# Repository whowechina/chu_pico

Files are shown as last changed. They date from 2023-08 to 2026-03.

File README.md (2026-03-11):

# Chu Pico - Chunithm Style Mini Controller
[点这里可以切换到中文版](README_CN.md)

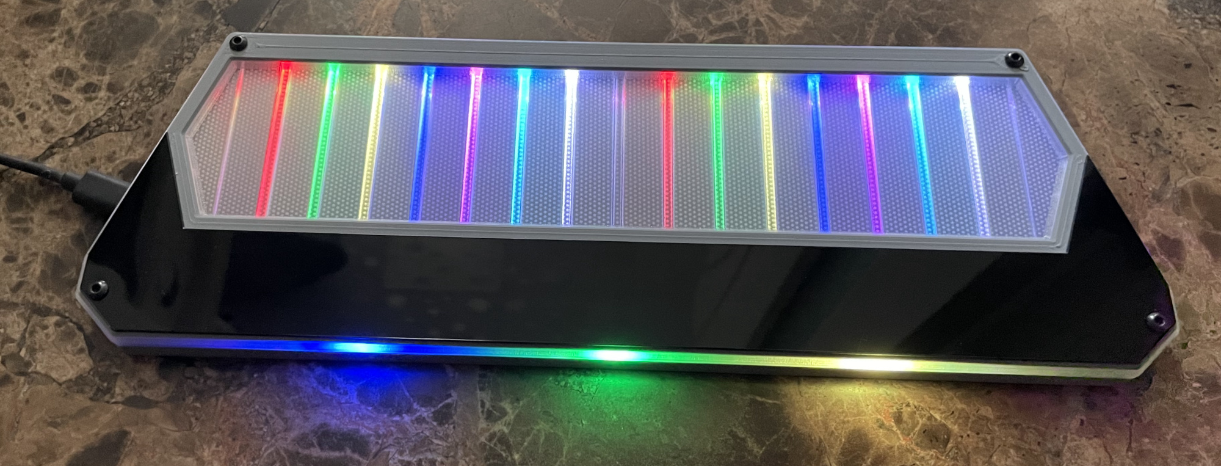
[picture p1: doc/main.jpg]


Features:
* It's small, made for 15-17 inch screen.
* Air towers are replaced with built-in ToF sensors.
* Traditional IR Air mechanism is also provided for DIYers.
* HID lights, of course!
* 32 keys (upper and lower rows).
* Follows CrazyRedMachine's RedBoard I/O protocol.
* Command line of rich features.
* All source files open.

Thanks to many respectful guys/companies who made their tools or materials free or open source (KiCad, OnShape, InkScape, Raspberry things).

And thanks to community developers that inspired me and helped me: CrazyRedMachine (https://github.com/CrazyRedMachine), SpeedyPotato (https://github.com/speedypotato).

And also:
* RP_Silicon_KiCad: https://github.com/HeadBoffin/RP_Silicon_KiCad
* Type-C: https://github.com/ai03-2725/Type-C.pretty

## My Other Projects
You can check out my other cool projects.

               


* Popn Pico: https://github.com/whowechina/popn_pico
* IIDX Pico: https://github.com/whowechina/iidx_pico
* Chu Pico: https://github.com/whowechina/chu_pico
* Mai Pico: https://github.com/whowechina/mai_pico
* Diva Pico: https://github.com/whowechina/diva_pico
* AIC Pico: https://github.com/whowechina/aic_pico
* Groove Pico: https://github.com/whowechina/groove_pico
* Geki Pico: https://github.com/whowechina/geki_pico
* Musec Pico: https://github.com/whowechina/musec_pico
* Ju Pico: https://github.com/whowechina/ju_pico
* Bishi Pico: https://github.com/whowechina/bishi_pico
* Nos Pico: https://github.com/whowechina/nos_pico
* Voltex Pico: https://github.com/whowechina/voltex_pico
* Chord Pico: https://github.com/whowechina/chord_pico
* Dance Pico: https://github.com/whowechina/dance_pico
* Arcade Pico: https://github.com/whowechina/arcade_pico

## **Disclaimer** ##
I made this project in my personal time with no financial benefit or sponsorship. I will continue to improve the project. I have done my best to ensure that everything is accurate and functional, there's always a chance that mistakes may occur. I cannot be held responsible for any loss of your time or money that may result from using this open source project. Thank you for your understanding.

## About the License
It's CC-NC. So DIY for yourself and for your friend, don't make money from it. And plagiarism that doesn’t even dare to mention the original author is not acceptable. Please note that pooling orders and group buying for raw materials is acceptable.Selling any leftover components at cost (without profit) is also acceptable.

If you're interested in buying from me, or for commercial use, please contact me (Discord, QQ group, Goofish).
* My Discord Invitation: https://discord.gg/M8f2PPQFEA
* QQ Group: 854535476
* Goofish: whowe12345

## HOW TO BUILD
### Frequently Made Mistakes
Many DIY enthusiasts commonly make certain mistakes during the building process. Please proceed with extra caution to avoid these.
* **MISTAKE: Soldering everything together without conducting intermediate testing.**  
  Remember, even professional engineers can make mistakes. It becomes significantly harder to identify the root cause of a problem when all components are already assembled or soldered. Therefore, it's advisable to solder and test in stages. The firmware is designed to function correctly even with some components missing, which is good for testing.
* **MISTAKE: Neglecting to cut the ADDR pin trace on the MPR121 module.**  
  The MPR121 module in the market has the ADDR pin pre-connected to ground. But the board expects a floating ADDR pin, otherwise the ADDR pin will short the circuit. Please verify your "CUT" using a multimeter.
* **MISTAKE: Rushing to replace components when something fails.**  
  Sometimes people prematurely assumes that the Raspberry Pi Pico or other modules are faulty.
  Be aware that desoldering and soldering large SMD components is a challenging task. It carries the risk of damaging the component or the PCB board. Patience and caution are crucial. Look at the schematics and PCB design files and ask help from community first. Questioning the integrity of these components should be your last resort.
* **MISTAKE: Failing to properly solder the 2 USB pins of the Raspberry Pi Pico.**  
  These pins are at the bottom side of the PCB. It's a common oversight to either forget to solder them or to leave air bubbles during the process. To avoid this, solder slowly from one side of the hole, using minimal solder wire and a generous amount of flux.

### PCB
* Go JLCPCB and make order with the gerber zip file (latest `Production\PCB\chu_main_xxx.zip`), regular FR-4 board, black color, thickness is **1.6mm**.  
* 1x Rasberry Pico Pi Pico or Pico W.  
  https://www.raspberrypi.com/products/raspberry-pi-pico
  Becareful of 3 pins that are at the other side, they're difficult to solder and may leave air bubbles.  
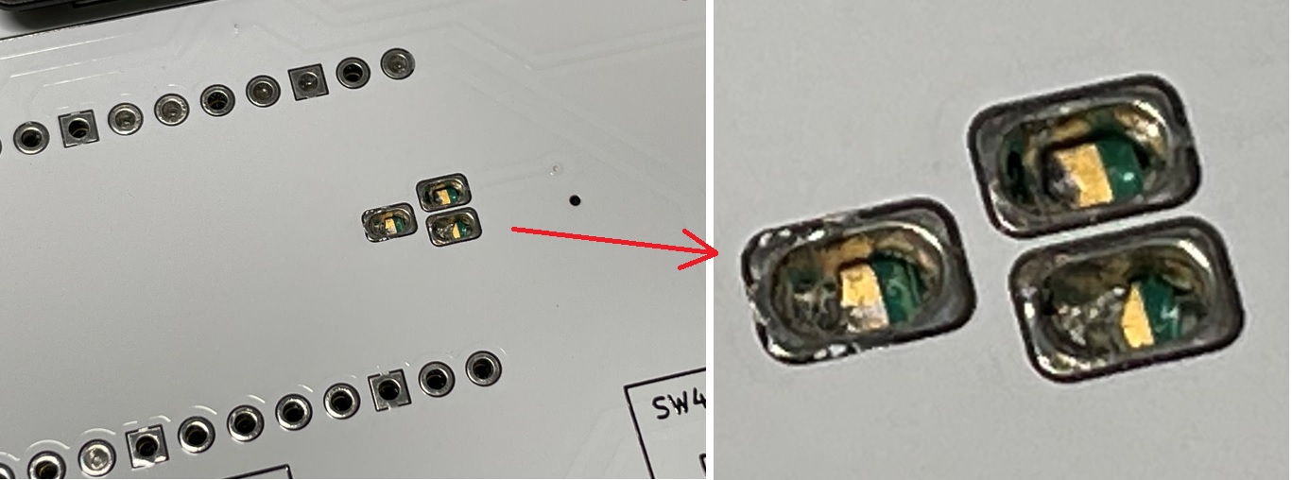
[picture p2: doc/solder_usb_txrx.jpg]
  

* 1x USB Type-C socket (918-418K2023S40001 or KH-TYPE-C-16P)
* 36x WS2812B-4020 side-facing RGB LEDs.  
  https://www.lcsc.com/product-detail/Light-Emitting-Diodes-LED_Worldsemi-WS2812B-4020_C965557.html
* TCA9548APWR (TSSOP-24) I2C multiplexer.  
  https://www.lcsc.com/product-detail/Signal-Switches-Encoders-Decoders-Multiplexers_Texas-Instruments-TCA9548APWR_C130026.html
* 3x MPR121 modules, there're many types in the market, choose ones like this.  
  https://www.sparkfun.com/products/retired/9695  
  Before solder MP121 module to the main PCB board, remember to use a knife to **cut (unshort) the tiny trace that connects ADDR to the GND**. Please be careful not to cut more than necessary.  
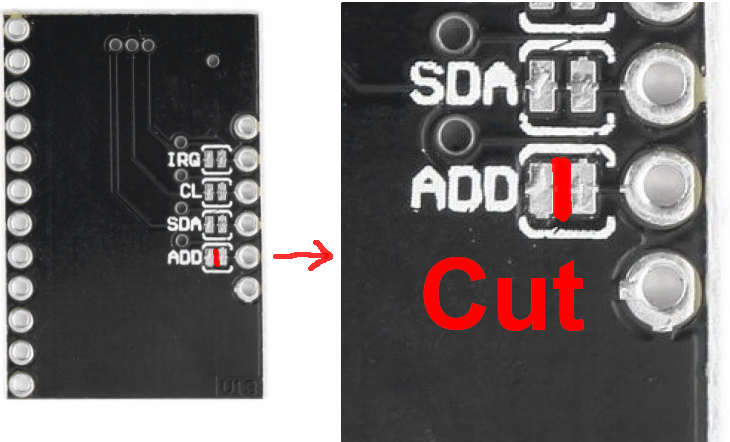
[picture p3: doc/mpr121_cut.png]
    
  There's not enough space for the whole height of MPR121 module plus the lead pads. So you need to solder the module like the picture shows below.  
  First apply some insulation tape.  
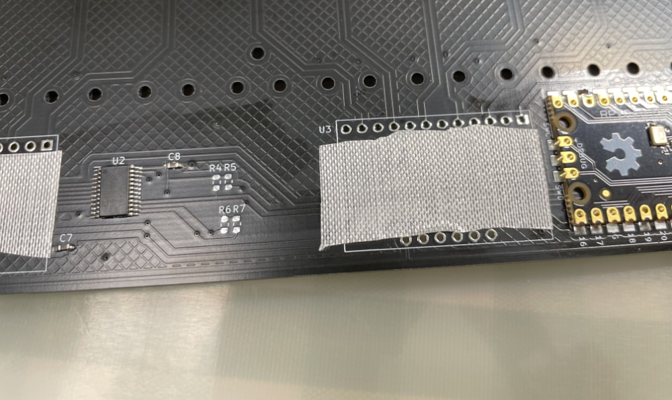
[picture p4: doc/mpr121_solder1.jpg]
    
  Then solder the module directly against the PCB.  
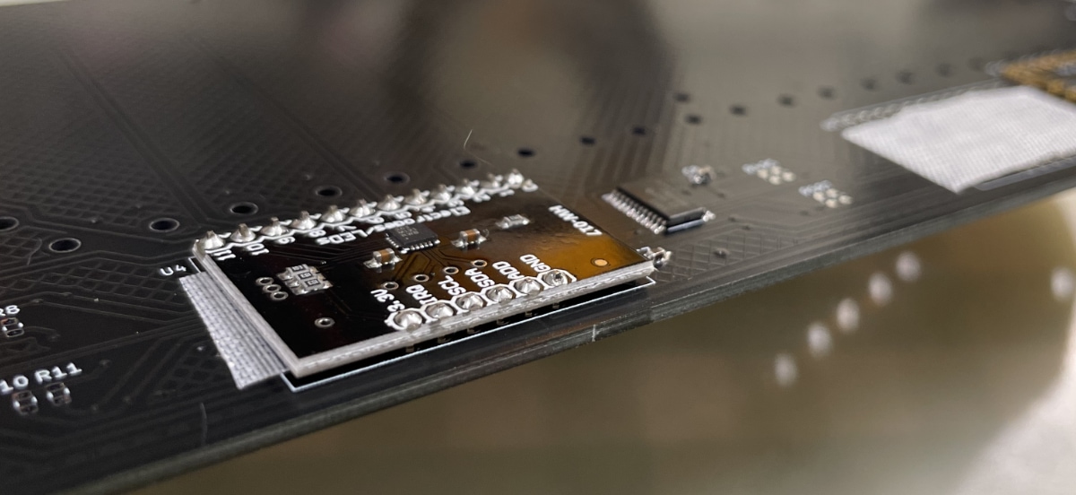
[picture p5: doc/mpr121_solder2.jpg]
    
  You can use the pins comes with the module, but you need to cut away the plastic pads.  
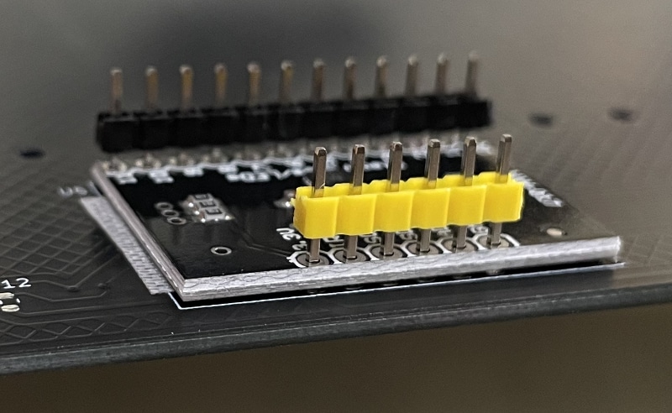
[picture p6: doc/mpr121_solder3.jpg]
  
* 5x Sharp GP2Y0E03 or ST VL53L0X ToF sensor modules, you need cables as well. Please note that the pictures are taken from older version of PCB, the LEDs have been changed to side-facing ones.  
  https://www.lcsc.com/product-detail/Angle-Linear-Position-Sensors_Sharp-Microelectronics-GP2Y0E03_C920270.html  
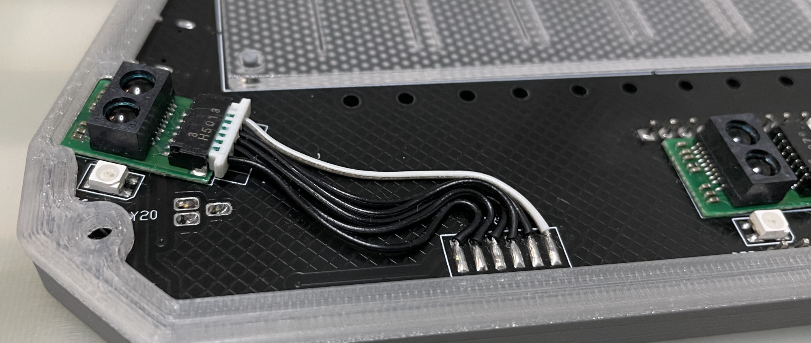
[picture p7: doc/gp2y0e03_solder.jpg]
    
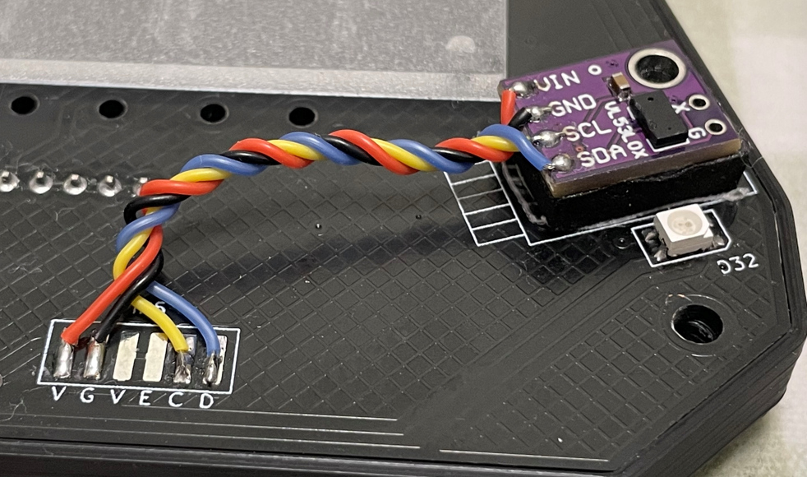
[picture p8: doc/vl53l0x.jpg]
    
   You can use both of them in a same PCB, the firmware will identify each of them automatically.  
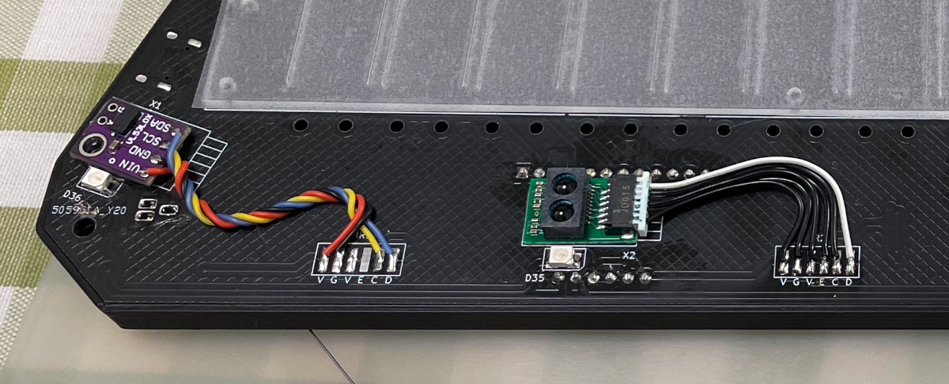
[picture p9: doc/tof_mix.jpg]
  
* 12x 0603 5.1kohm resistors for all the resistors on PCB.
* 8x 0603 1uF (0.1~1uF all fine) capacitors (C1 to C8), OPTIONAL, recommended.
* 3x Panasonic EVQP46B3M tiny tactile switches.  
  https://industry.panasonic.com/global/en/products/control/switch/light-touch/number/evqp46b3m

### Light Guide Panel
* Find a service to cut a light guide panel using DXF or DWG file `Production\CAD\chu_pico_lgp.*`, the size is 256mm*60mm, 1.8mm to 2.0mm thickness, thinner is better for sensitivity. 2.0mm is easy to find, 1.8mm is rare. I used 1.8mm for my build.  
  
* LGP material choices:
  * Real LGP (Light Guide Panel) material, it's the best choice.  
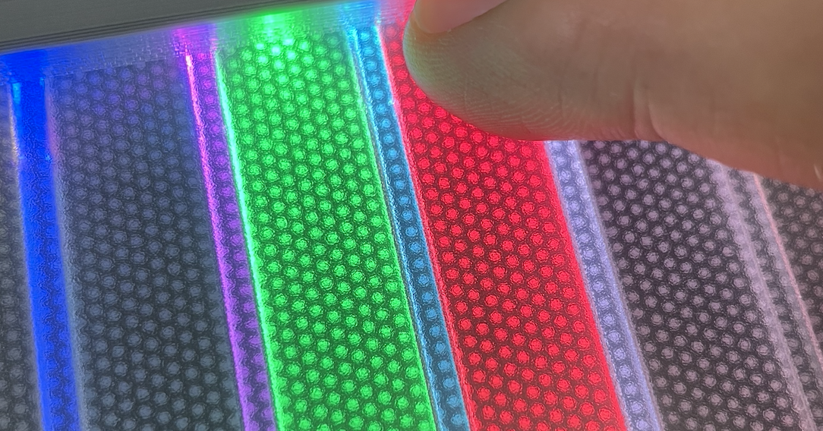
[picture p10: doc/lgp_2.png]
    
  * Clear Acrylic with Light Guide Film, it's a good choice.  
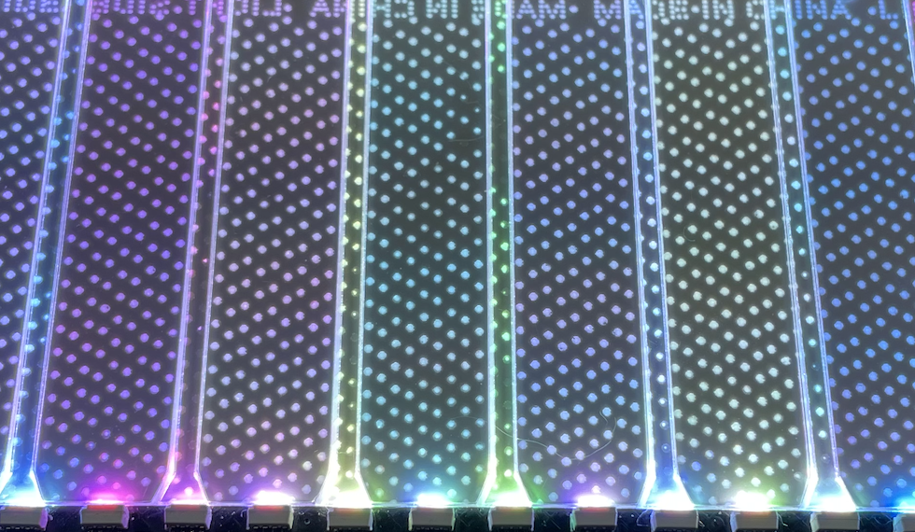
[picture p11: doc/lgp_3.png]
    
  * Clear Acrylic with single-side-frosted, it's a good choice.  
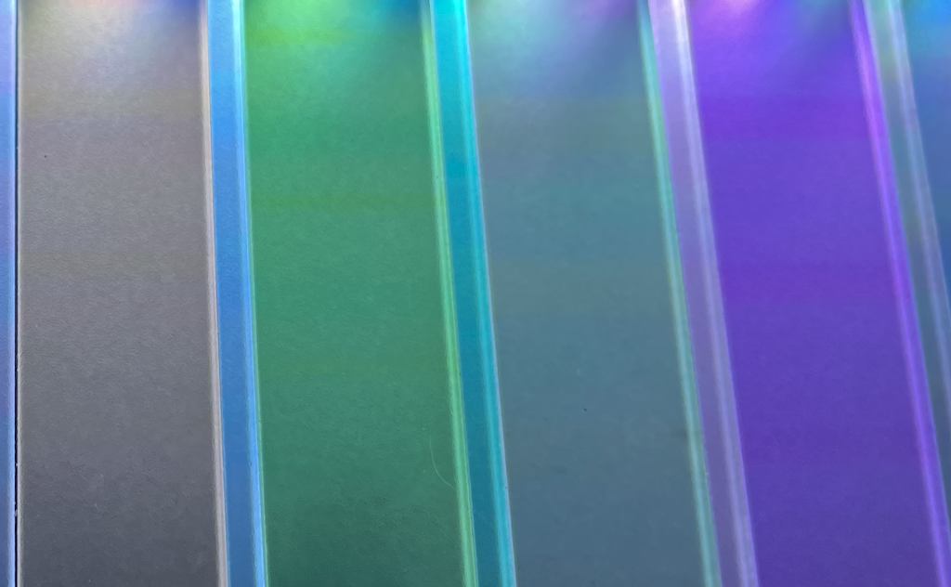
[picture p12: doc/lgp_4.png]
    
  * Clear Acrylic with manual single-side-sanding, it can work too.  
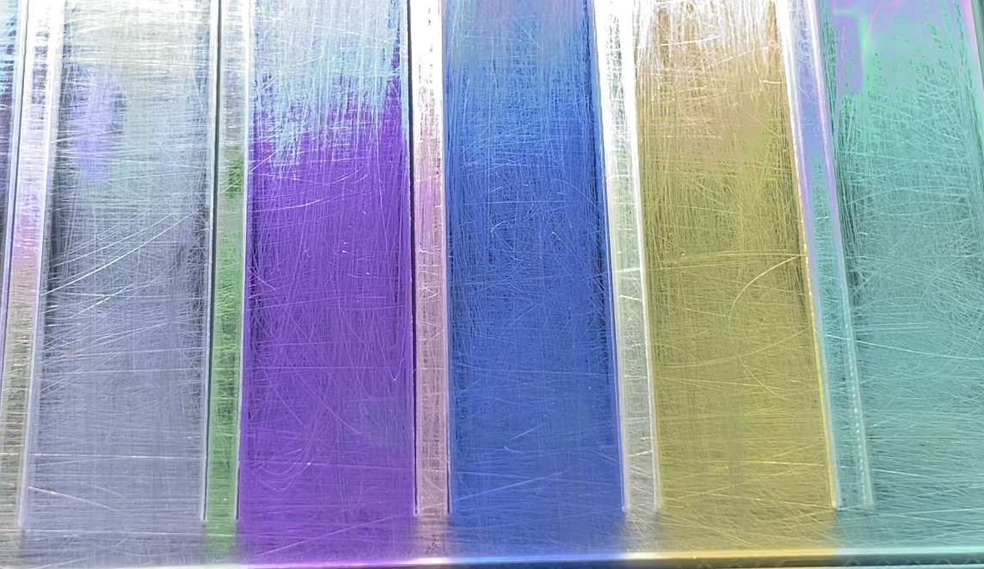
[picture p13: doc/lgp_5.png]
    

### Panel Film
* A self-adhesive **textured**/**frosted** film sheet, it is applied on top surface of the light guide panel. It improves touch feel. You can use window sticker film. It **MUST** be self-adhesive ones, **NOT** static cling ones. They're usually very cheap.
* Cut the film to roughly match the shape of the light guide panel, and stick to the panel.  
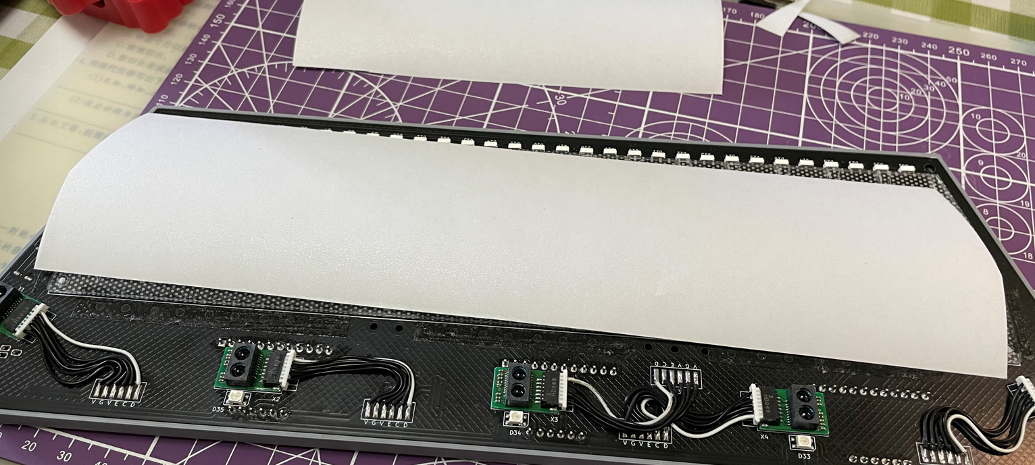
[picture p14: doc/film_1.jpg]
  
* Gentlely rub the film to remove any air bubbles and make it stick tightly.  
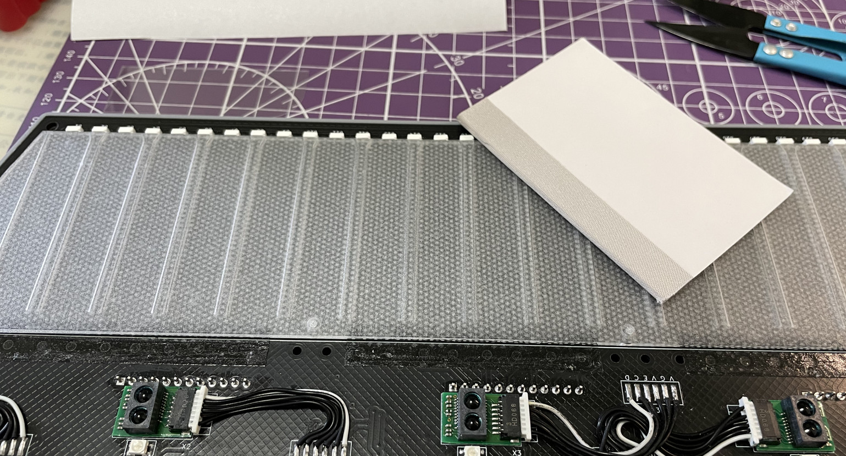
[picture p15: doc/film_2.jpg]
  

###  IR Cover
* It's for good looking, as it hides 5 ToF sensors.   
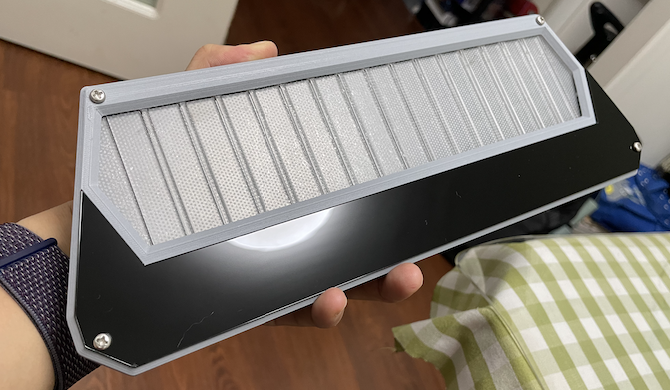
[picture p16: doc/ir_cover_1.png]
  
* IR lights can go through.  
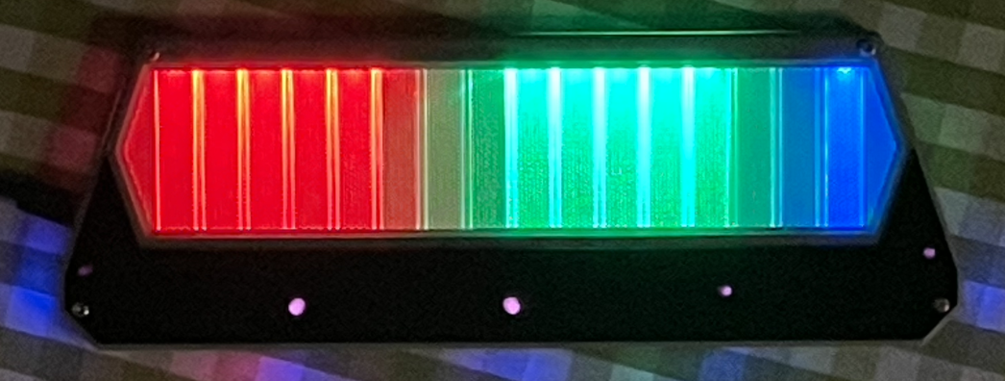
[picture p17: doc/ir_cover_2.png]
  
* Find a service to cut an IR cover using the DXF or DWG file `Production\CAD\chu_pico_ir_cover.*`, the size is 293.2mm*63.5mm, 1mm thickness. The material must be "Infrared Transmitting Acrylic Sheet" which can block visible lights (so it looks black) while letting IR lights go through.  
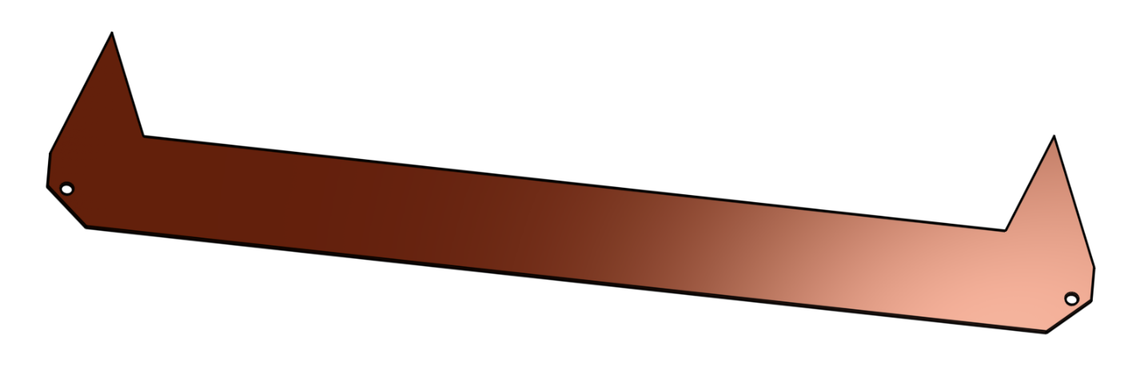
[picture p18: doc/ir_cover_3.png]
  
* If you can't find one, cut a regular smooth surface acrylic, but it can't hide the ToF sensors which are not good looking.
* If you're using the VL53L0x ToF sensor, please add padding beneath the sensor. This brings it closer to the acrylic cover, which can prevent acrosstalk error.

### 3D Printing
* You need a Bambu 3D printer for 2 reasons:
  * Parts are designed to perfectly fit in its 256mm*256mm print bed.
  * Its AMS system works great for easy-to-remove support material.
* For all the following prints:
  * To fit object in the bed, Z rotate: 315 degree, X, Y move to: 134mm  
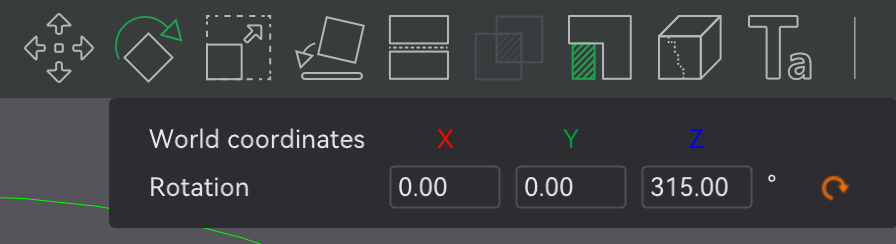
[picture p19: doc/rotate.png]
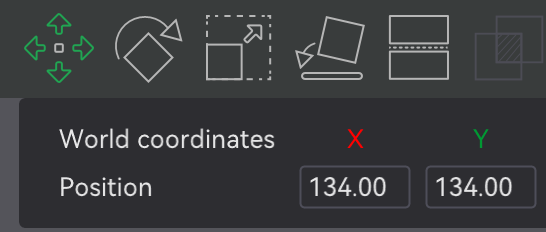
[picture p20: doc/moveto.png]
    
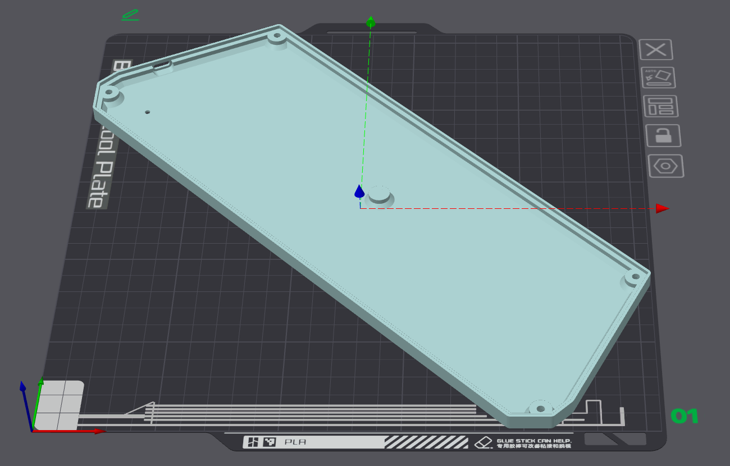
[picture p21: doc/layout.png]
  
  
  * PLA, PETG, ABS are all OK.
  * Layer height: 0.2mm
  * 4-6 walls, 50+% infill
  * Support: No (unless specified).

* Base: `Production\3D\chu_pico_base.stl`, dark gray filament, turn on support to have better screw holes.
* Cover: `Production\3D\chu_pico_cover(_aime).stl`, dark gray filament, print up-side down.
* Cover Base: `Production\3D\chu_pico_cover_base.stl`, **clear transparent (IMPORTANT)** filament.
* Light Guide Panel Fixer: `Production\3D\chu_pico_lgp_fixer.stl`, color doesn't matter.

### Exploded View for Assembly
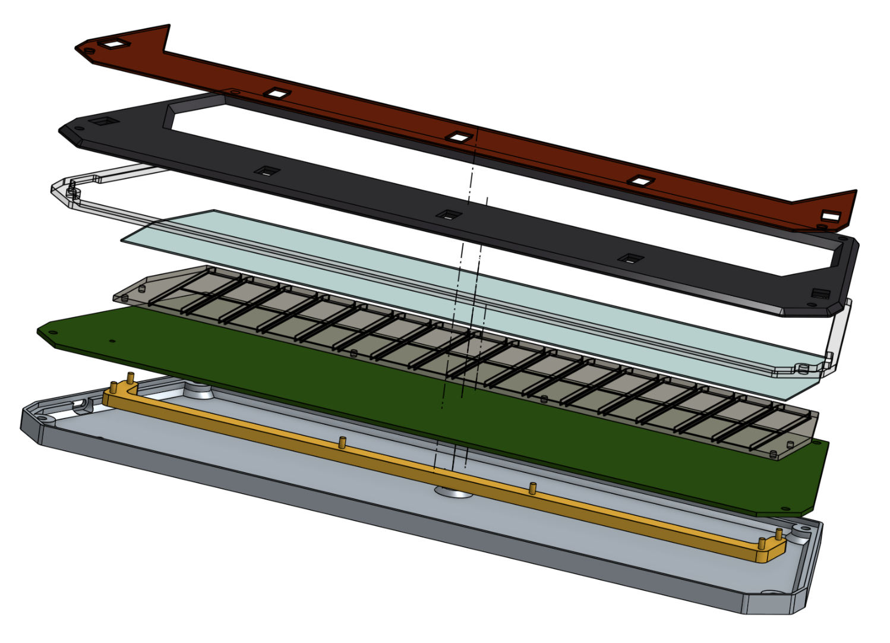
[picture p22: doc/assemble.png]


From top to bottom:
* IR Cover
* Cover
* Cover Base
* Panel Film
* Light Guide Panel
* PCB
* Light Guide Panel Fixer
* Base

You need **4x M3*12mm screws and 4x M3 hex nuts** to fix all things.

7x silicone anti-slip pads can be applied to the bottom side of the base to provide stability when playing.  
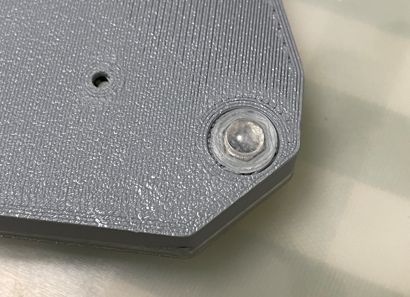
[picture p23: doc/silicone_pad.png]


### IR Air Tower
This is not necessary for Chu Pico. But some people may prefer the traditional IR air tower, especially when they're using Chu Pico design for a full-sized controller.
So hereby I provide the IR air tower design, with a pair of air tower PCBs and the firmware support.
1. First, you need to order the sensor PCBs, the gerber file is `Production\PCB\chu_air_v*.zip`. It's for both sides of the air tower.
2. Solder components to the PCB following the silkscreen. About the components, see the notes below.
3. For left side PCB, use J1 to connect to the Raspberry Pi Pico, and for the right side PCB, use J2. GPIO 3 -> A, GPIO 4 -> B, GPIO 5 -> C, ADC 0 (GPIO 26) -> Right S, ADC 1 (GPIO 27) -> Left S.  
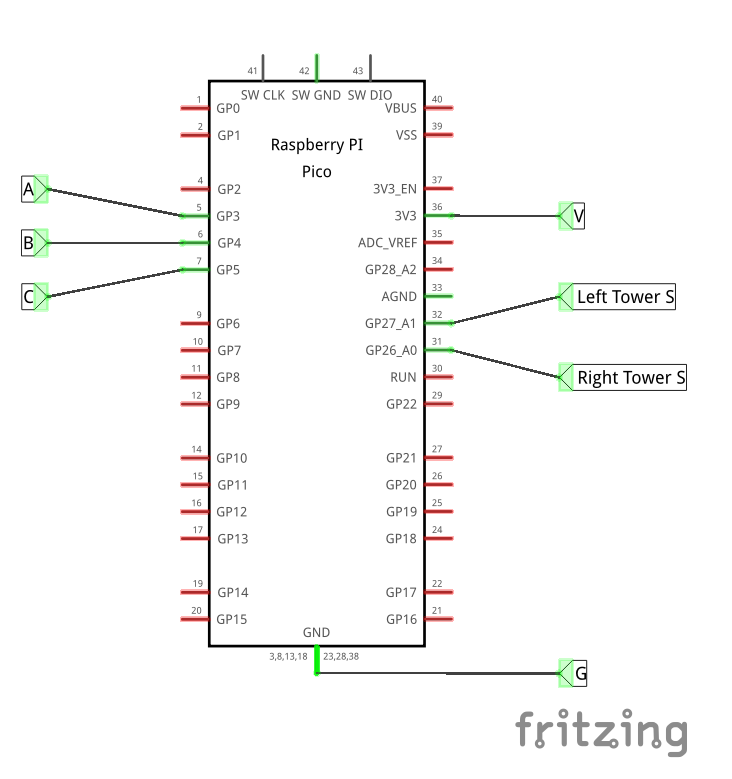
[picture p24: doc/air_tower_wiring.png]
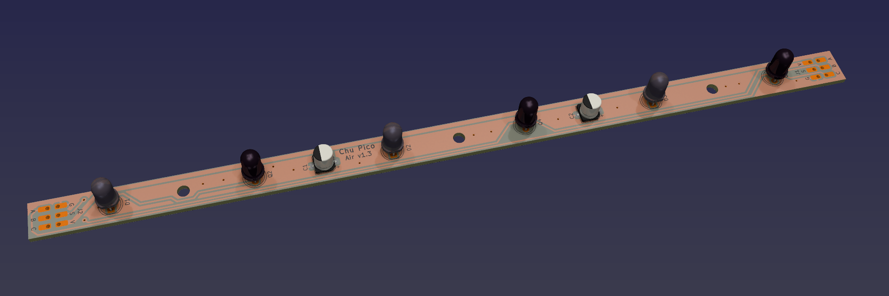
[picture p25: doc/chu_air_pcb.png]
   

4. Steps for deployment.
   * Enable IR sensor in the firmware (command `ir enable`), this will disable ToF.
   * Enable diagnostics for IR (command `ir diagnostic`).
   * Orientation of the PCB: for the left side PCB, its J1 is at the lowest, for the right side PCB, its J2 is at the lowest (up-side-down).
   * Place the air towers and watch the output of the diagnostics, higher value means beam is received.
   * Set the baseline after the towers are properly placed (command `ir baseline`).
   * Optionally, set the sensitivity, it's a percentage of expected change (command `ir trigger <1..100>`).

#### Notes for the Components
* D1, D2, D3 are IR333C-A IR LEDs;
* Q2, Q4, Q6 are PT333-3B phototransistors.
* Q1, Q3, Q5 are N-Channel MOSFETs with low Rds, such as AO3400, see calculations below.
* R2, R4, R6 are current limiting resistors, see calculations below.
* R1, R3, R5 are mosfet gate resistors, 10ohm is fine.
* R7, R8, R9 are pull-up resistors, 2Kohm is fine.
* R10 is a pull-down resistor, 10Kohm is fine.

* Let's do the calculation for D1 as an example. To get proper signal strength, we want about 1A current for it.  
  The current for D1 is calculated by `I = (Vcc - Vf) / (Rds + R2)`. Vcc is 3.3V, Vf is the forward voltage of D1 (about 2.6V@1A). For a low Rds N-Channel MOSFET such as AO3400, Rds is about 0.047ohm, so R2 should be about 0.7ohm to get 1A current. You can use other N-Channel MOSFETs, but you need to calculate the values accordingly.

### Firmware
* UF2 file is in `Production\Firmware` folder.
* For the new build, hold the BOOTSEL button while connect the USB to a PC, there will be a disk named "RPI-RP2" showed up. Drag the UF2 firmware binary file into it. That's it. There's a small hole at the bottom side of the Chu Pico, it is facing right to the BOOTSEL button.
* It works on CrazyRedMachine's RedBoard protocol. For more information, please check out CrazyRedMachine's project (Don't forget to give him a star and drop by his GitHub for other cool projects):  
https://github.com/CrazyRedMachine/RedBoard
* It has a command line to do configuration. You can use this Web Serial Terminal to connect to the USB serial port of the Chu Pico. (Note: "?" is for help)  
  https://googlechromelabs.github.io/serial-terminal/  
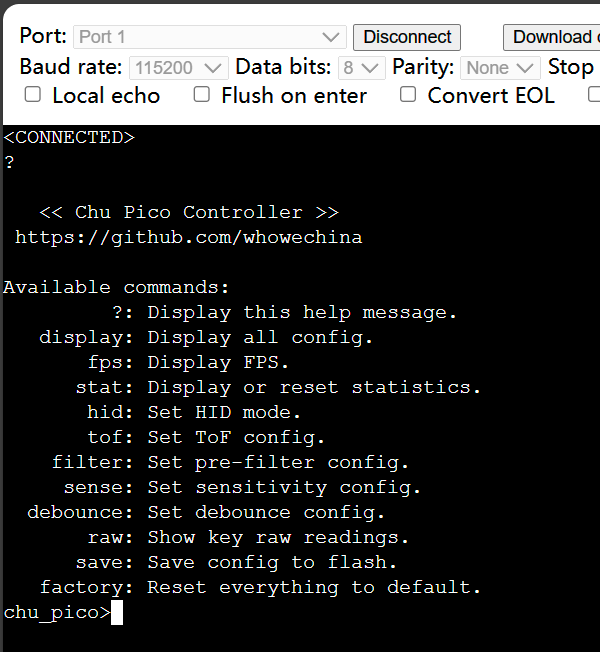
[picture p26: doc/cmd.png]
  

## CAD Source File
I'm using OnShape free subscription. It's powerful but it can't archive original designs to local, so I can only share the link here. STL/DXF/DWG files are exported from this online document.  
https://cad.onshape.com/documents/8b9d0fe6ff1bfa4da17d33ee/w/5c7c980a282a19e7ba1db795/e/56ee65492584a3f709c23c49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

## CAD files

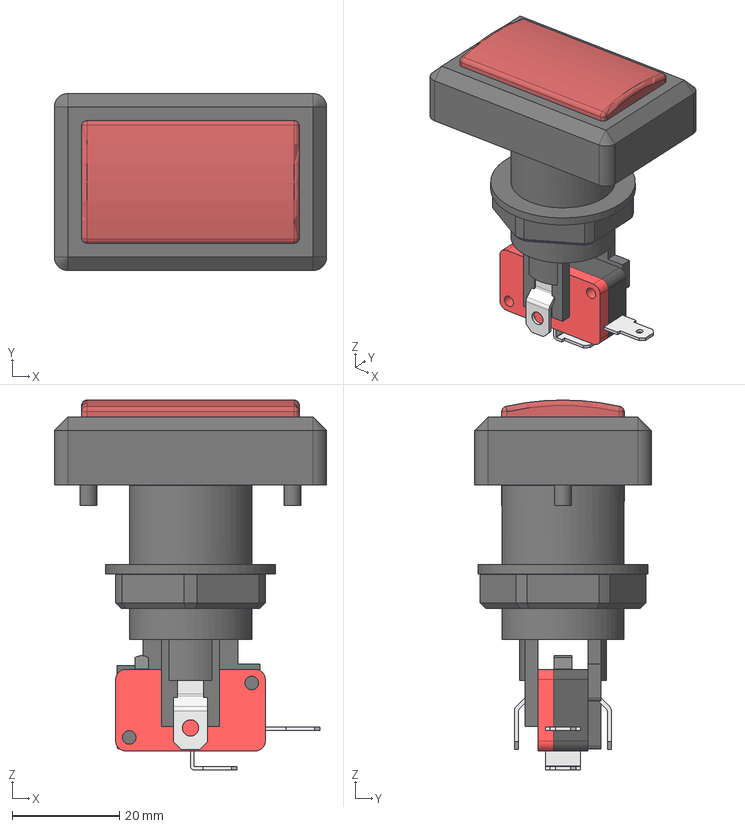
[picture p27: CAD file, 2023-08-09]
PCB/main/3dmodels/Credit Button Assy (Groovy).step
50.8 x 33.0 x 69.0 mm
Button
Nut
Switch

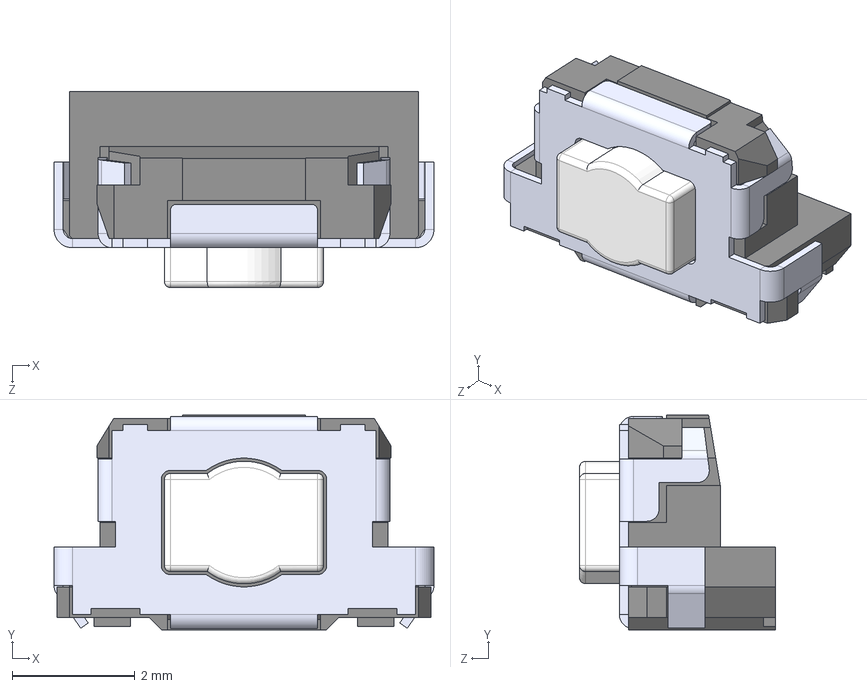
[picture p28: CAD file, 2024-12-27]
PCB/main/3dmodels/EVQ-P46B3M.step
6.20 x 3.50 x 3.20 mm

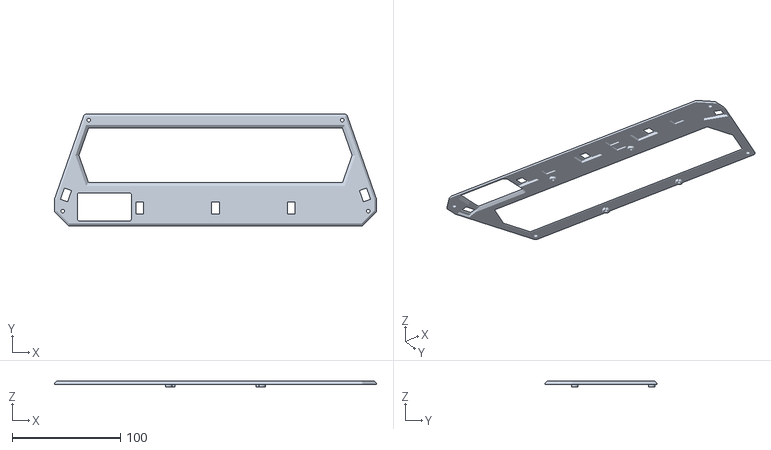
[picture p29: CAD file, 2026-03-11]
Production/CAD/chu_pico_cover_aime.stl
297.2 x 103.2 x 5.20

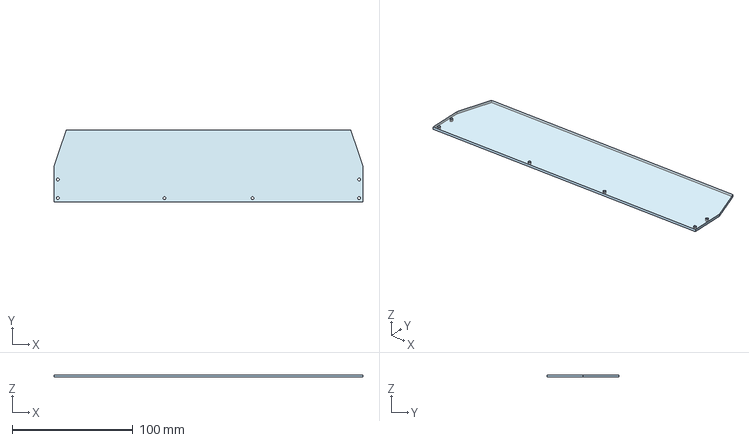
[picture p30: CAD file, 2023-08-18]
PCB/main/3dmodels/chu_keypad_lgp.step
256.0 x 60.0 x 2.00 mm

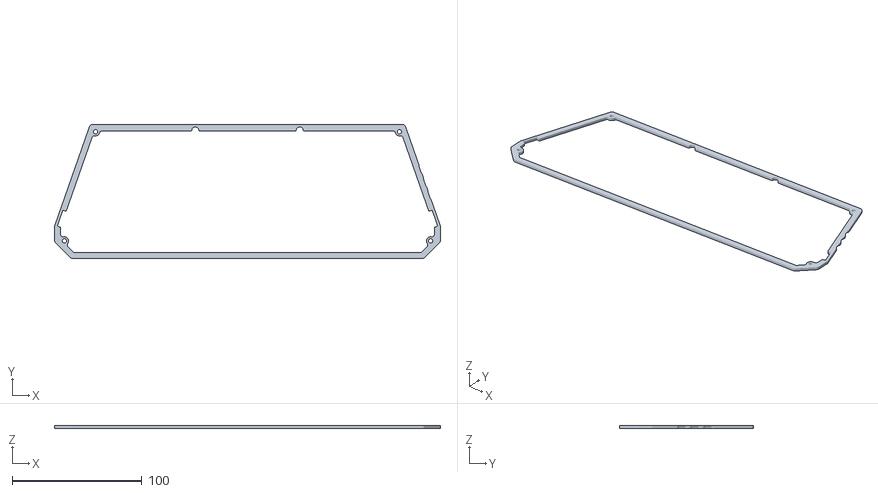
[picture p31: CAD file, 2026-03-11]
Production/CAD/chu_pico_support.stl
297.2 x 103.2 x 2.20

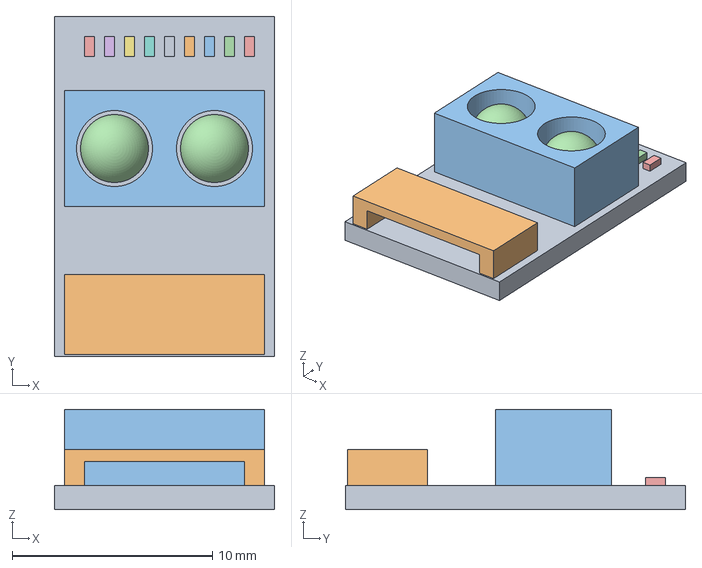
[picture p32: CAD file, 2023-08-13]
PCB/main/3dmodels/gp2y0e03.3mf
11.0 x 17.0 x 5.00 mm

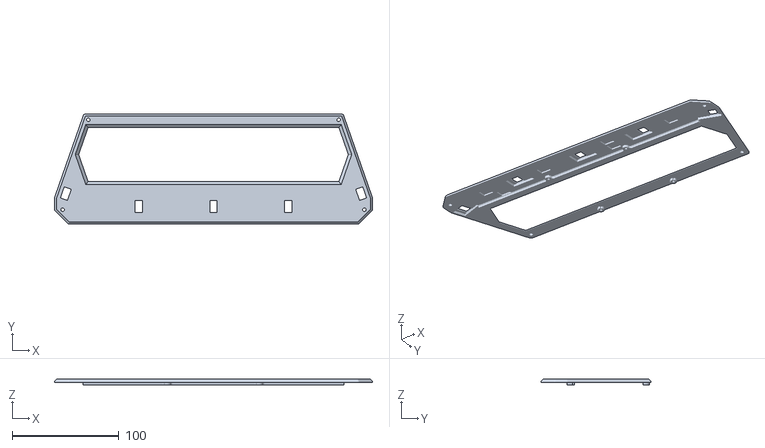
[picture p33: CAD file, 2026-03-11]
Production/CAD/chu_pico_cover.stl
297.2 x 103.2 x 5.20

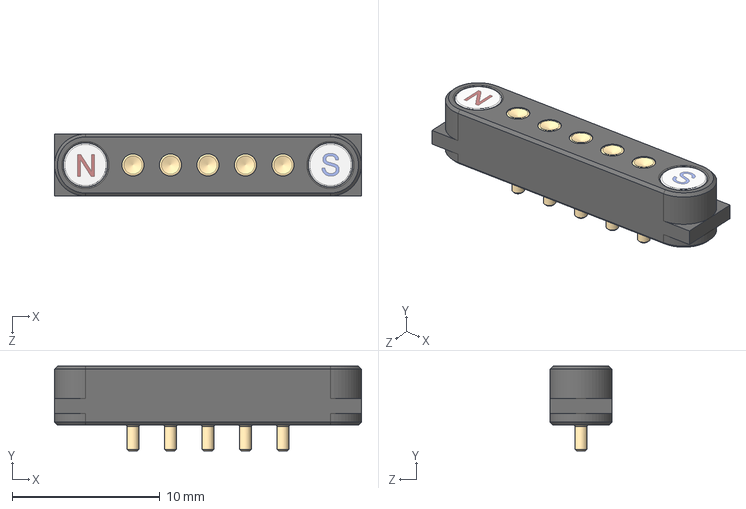
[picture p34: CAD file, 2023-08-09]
PCB/main/3dmodels/Magnetic Pogo Connector 5 Pin (F).STEP
20.8 x 5.75 x 4.20 mm

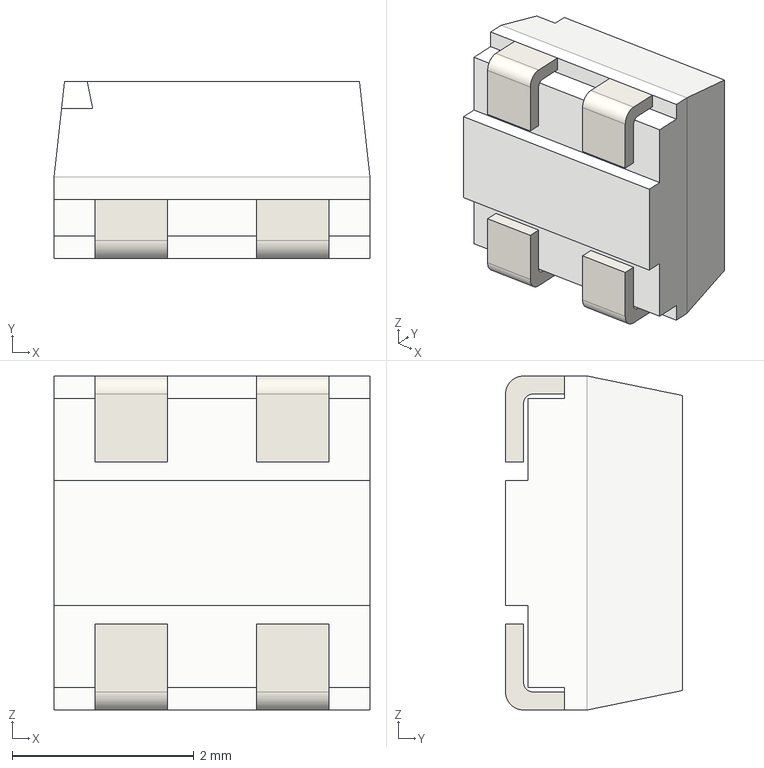
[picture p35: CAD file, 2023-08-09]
PCB/main/3dmodels/SMD WS2812B-3535.step
3.48 x 1.95 x 3.68 mm

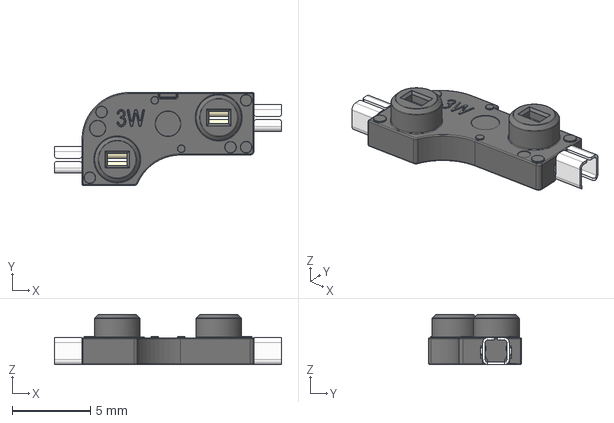
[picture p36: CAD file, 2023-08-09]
PCB/main/3dmodels/SW_Hotswap_Kailh_MX.stp
14.5 x 5.95 x 3.22 mm

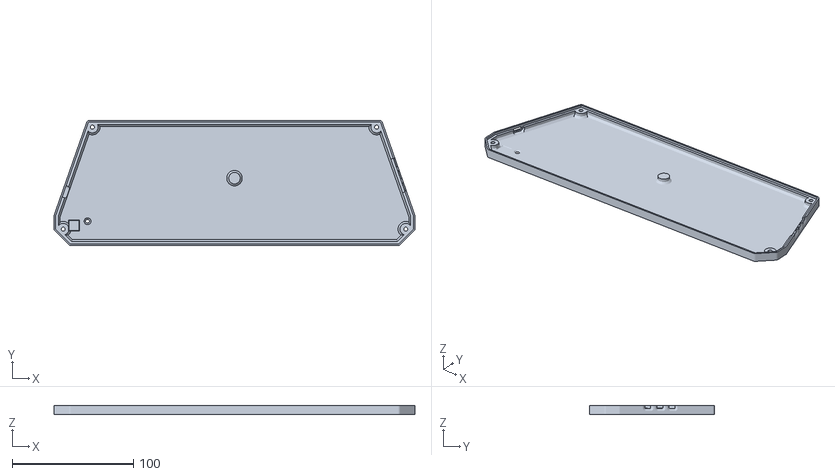
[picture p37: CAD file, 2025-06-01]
Production/CAD/chu_pico_base.stl
297.2 x 103.2 x 7.20

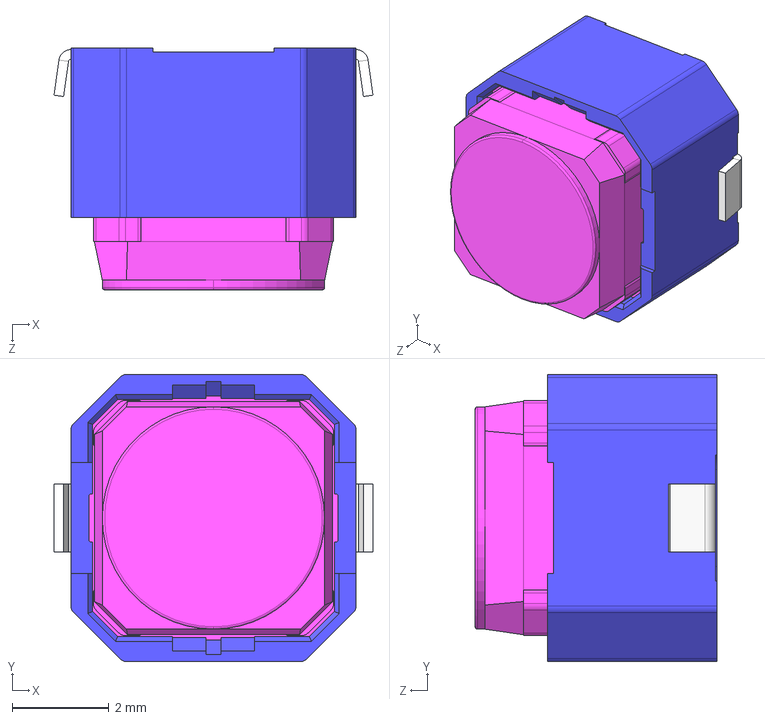
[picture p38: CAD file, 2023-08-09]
PCB/main/3dmodels/SKPMAM.STEP
6.60 x 5.94 x 5.00 mm

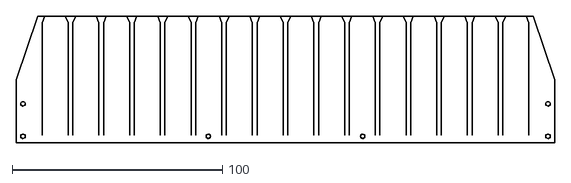
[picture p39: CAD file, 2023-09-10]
Production/CAD/chu_pico_lgp.dxf
256.0 x 60.0

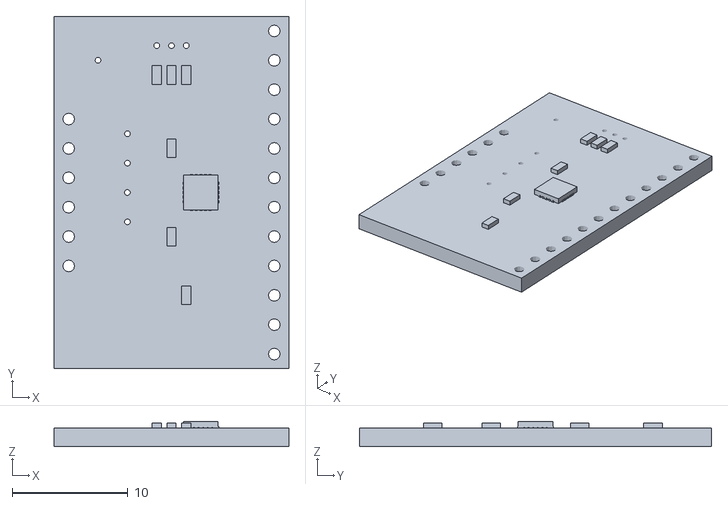
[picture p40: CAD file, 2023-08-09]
PCB/main/3dmodels/mpr121_breakout_v13.stl
20.3 x 30.5 x 2.20

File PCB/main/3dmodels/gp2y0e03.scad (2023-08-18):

$fn=64;
translate([-5.5,-8.5]) color("darkgreen") cube([11,17,1.2]);

color("#202020") difference() {
  translate([-5,-8.4]) cube([10,4,3]);
  translate([-4,-9.3]) cube([8,4,2.4]);
}

color("#303040") difference() {
  translate([-5,-1]) cube([10,5.8,5]);
  translate([2.5,1.9,3]) cylinder(d=3.8,h=10);
  translate([-2.5,1.9,3]) cylinder(d=3.8,h=10);
}
color("#602020") {
  translate([2.5,1.9,3.2]) sphere(d=3.4);
  translate([-2.5,1.9,3.2]) sphere(d=3.4);
}
  
for (i = [-4:1:4]) {
  color("yellow") translate([i,6.5,1]) cube([0.5,1,0.6]);
}

for (i = [-4:1:4]) {
  color("silver") translate([i-0.2,-1.8,0.8]) cube([0.5,1,0.6]);
  color("silver") translate([i-0.2,4.6,0.8]) cube([0.5,1,0.6]);
}

for (i = [-4:1.3:4]) {
  color("silver") translate([i-0.3,-5,1]) cube([0.6,2,0.6]);
  color("silver") translate([i-0.6,-7,2]) cube([0.2,2,0.6]);
}

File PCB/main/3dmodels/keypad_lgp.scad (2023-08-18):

color("silver",0.5) translate([-17,-130]) resize([256,60,1]) linear_extrude(h=100) import("keypad_kicad.svg");

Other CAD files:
PCB/main/3dmodels/iidx_keycap_main_step.stp
Production/CAD/chu_pico_cover_insert.stl
Production/CAD/chu_pico_cover_insert_aime.stl
Production/CAD/chu_pico_ir_cover.dxf
PCB/main/3dmodels/EVQ-P1D05M.stp
PCB/main/3dmodels/J 2835.step
PCB/main/3dmodels/Kailh LP Choc PC Keycap.step
PCB/main/3dmodels/Magnetic Pogo Connector 5 Pin (M) - 副本.STEP
PCB/main/3dmodels/Magnetic Pogo Connector 5 Pin (Type 2).STEP
PCB/main/3dmodels/Magnetic Pogo Connector 5 Pin (Type 3).STEP
PCB/main/3dmodels/Magnetic Pogo Connector 5 Pin (Type 4).STEP
PCB/main/3dmodels/SW_Hotswap_Kailh_Choc_V1.stp
PCB/main/3dmodels/SW_Kailh_Choc_V1.stp
PCB/main/3dmodels/Tact Switch 4.5mm SMT.step
PCB/main/3dmodels/User Library-PTS645SL95SMTR92-LFS.STEP
PCB/main/3dmodels/User Library-WS2812-2020.step
PCB/main/3dmodels/User Library-WS2812-4020.step
PCB/main/3dmodels/User Library-pj-393-8.STEP
PCB/main/3dmodels/WS2812-0807.STEP
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

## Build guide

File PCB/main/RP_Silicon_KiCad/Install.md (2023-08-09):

# Install KiCad libraries

## Manage Symbol Libraries

Accessed from the Preferences menu, add a new line with the +, give it a name and use the folder icon to point to the directory/folder where you have KiCadLibraries.

Manage Symbol Libraries screen shot


## Manage Footprint Libraries

Ditto! Accessed from the Preferences menu, add a new line with the +, give it a name and use the folder icon to point to the directory/folder where you have KiCadLibraries.

Manage Footprint Libraries screen shot


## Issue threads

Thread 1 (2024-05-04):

is there a proper tutorial or method

zendon180, 2024-05-04:
just the title

zendon180, 2024-05-04:
also how does it register input? there is no touch sensor?

whowechina, 2024-05-04:
Of course there's touch sensor: capactive sense.
The readme in both EN and CN is the guide telling you how to build one.
But there won't be anything related to game data related thing.

zendon180, 2024-05-05:
oh wait i think my question was wrong what i meant to say is something more like, the touch sensors aren't under the keys so how does it register?

whowechina, 2024-05-05:
I see. So it's about "how the touch sensors work". The touch sensors (electrodes) are actually under the slider panel, built-in with the PCB. Search for MPR121 datasheet, or search "capsense", you'll understand.

zendon180, 2024-05-06:
thanks for the response i was thinking if it was something like that

Closed 2024-05-04.

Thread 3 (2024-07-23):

chuniio.dll problem

sksjndn3, 2024-07-23:
i edit segatools io to [chuniio.dll](urlhttps://github.com/whowechina/chu_pico/blob/main/tools/chuniio.dll) and the game even cannot run,the error see as the photo
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

sksjndn3, 2024-07-23:
用的tools里的chuniio.dll，怎么试都报这个错

whowechina, 2024-07-23:
跑的是 redboard 的协议，用 redboard.dll。

Closed 2024-07-23.

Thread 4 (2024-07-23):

LED problem

sksjndn3, 2024-07-23:
Chinese plz。
刷了led测试程序，在d13就不亮了，万用表测了下正常导通，灯也换了好几个，就是d13往后都不亮，是不是程序有问题
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

whowechina, 2024-07-23:
信号是串联传递的，一般 D13 故障，就要同时看 D12/D13 的焊接。

sksjndn3, 2024-07-23:
我用万用表打了导通挡，全引脚都是正常导通的，还是不亮

sksjndn3, 2024-07-23:
我再排除一下吧，谢谢大佬回复

whowechina, 2024-07-23:
> 我再排除一下吧，谢谢大佬回复

除了“通”，要关注不应该通的，比如 D12 通往 D13 的数据线，不应该碰上 G 或者 V。

Closed 2024-07-23.

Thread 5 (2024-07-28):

i2c/touch problem

sksjndn3, 2024-07-28:
我在焊接完毕后，烧录chupico固件后注意到灯乱闪，然后拆焊下来，在chuntest测试程序里发现一直在凭空触发所有区块，随后我又拿了一片完全全新的树莓派pico烧录chupico固件，也是这样乱跳，我找不到解决方案，多次重刷固件也无果
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

whowechina, 2024-07-29:
Touch 传感由 MPR121 模块完成，这个模块未连接或者连接故障就会导致错误的触摸检测。
使用命令行里面的多个命令，尤其是“raw”来进行调试，正常情况下，各个电极感应数据都在 850-900 附近。
因为这个不是 Chu Pico 本身的问题，我就关闭这个 Issue 了。

sksjndn3, 2024-07-29:
好的吧，那我再排查一下3个mpr模块的问题，不过之前焊的两片板子都是通电正常亮灯来着

sksjndn3, 2024-07-29:
也不对吧，我先前焊的四片pcb都是先测灯光完好性再焊触摸模块的，也没这样抽风闪灯😢

whowechina, 2024-07-29:
灯光测试有一个专门的 UF2 文件，它不读触摸，仅仅点灯。
触摸模块或者 I2C 故障的时候，现象是随缘的。

sksjndn3, 2024-07-31:
这问题很玄乎啊，3片mpr都是没有故障的之前焊的板子都是先测灯再上触摸，也没见这种抽搐，上了完好触摸也无济于事，raw读数照样抽风，进test也乱闪
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

这是另一片没焊触摸，触摸灯光和raw读数完全正常
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

whowechina, 2024-07-31:
使用chu_pico_led_test.uf2进行led测试，这个固件也只能测试led。

触摸故障的话，记得mpr121模块本身坏的概率极其低，更多是焊接，割addr线等事情。电子制作嘛，啥失误都可能。

sksjndn3, 2024-07-31:
不对不对，我是说触摸数据在没有焊触摸模块的时候乱跳，这就说明锅甩不到mpr头上，何况焊了和没焊的乱跳表现都是一样的😞

whowechina, 2024-07-31:
没焊好，或者没挂模块，都是一回事，都是触摸故障。 具体现象根据i2c俩引脚环境随缘了。在 2024年7月31日，22:48，sksjndn3 ***@***.***> 写道：
不对不对，我是说触摸数据在没有焊触摸模块的时候乱跳，这就说明锅甩不到mpr头上，何况焊了和没焊的乱跳表现都是一样的😞

—Reply to this email directly, view it on GitHub, or unsubscribe.You are receiving this because you modified the open/close state.Message ID: ***@***.***>

Closed 2024-07-29.

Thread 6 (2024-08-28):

There's just two problem.

crazyforsf, 2024-08-28:
Using a translator. I'm Korean.

=================================================================

I think using a ToF sensor is a pretty good idea, but there are two problems with this form.

-
First, if the air sensor is being recognized in the 'center' and the touch has to be crossed with the other hand, the air sensor recognition is blocked by the other arm.
(ex : gengaozo expert, screenshot)
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

Of course, being aware of that part, I can move my hand to the air sensor, but it is quite difficult to do so during complex processing of high difficulty level - master level 13+ or higher.

Therefore, it is good to use a ToF sensor, but I think it would be a better choice to have separate key assignment options or builds for each sensor, rather than depending on the 'height' of the ToF sensor.
(By placing the ToF sensor sideways like a conventional IR sensor)

-
Secondly, this is not a problem for this small controller, but if you make a full size controller the number of tof sensors is not enough.

There are some empty spaces in between.

Therefore, it is judged to be a good idea to allocate the maximum connection value of the TCA9548APWR chip to the ToF sensor. From the current 5 to the maximum of 8.

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

This is Openithm+chupico, which I created by modifying various things myself.
(Never mind that there are six sensors. It's not working right now so I've reduced it back to 5.)

It's arcade full size, and I think it works pretty well.

===================================================================

This is just a suggestion, and there is no pressure to ask why not make the offer.
I just think it would be better if these areas were improved.

whowechina, 2024-08-28:
Hey, thanks for the feedback.
For the first problem, I can't do anything so far. Honestly I don't see a solution there for such a small con.
For the second problem, you can check my chu_arcade repo. I used 10+ ToF sensors for my arcade size con.

https://github.com/user-attachments/assets/cb141b87-1fb6-4556-abc9-fbacf5f58e4d

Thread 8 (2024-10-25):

air乱序

ifaming, 2024-10-25:
你好，我发现使用tof模式下的air从下往上触发顺序是2 3 4 1 5 6，而不是1 2 3 4 5 6，这是故意这样设计的还是说这是一个bug？

whowechina, 2024-10-26:
按照 redboard chunio 来的。

whowechina, 2024-10-26:
我确认后会修改。

whowechina, 2024-11-02:
感谢，确实有问题，我已经修复。

Thank you. I've fixed it in latest commit.

Closed 2024-11-02.

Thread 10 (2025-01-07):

tof sensors not working

GuardianGuy, 2025-01-07:
I'm using [these](https://www.aliexpress.us/item/3256807013376106.html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) ST VL53L0X tof sensors (the blue ones) and I can't get them to sense anything, the CLI shows them all at 0 no matter what I put in front of them or what I set the offset or pitch to.  The rest of the controller works as intended and I've checked and re-checked the wiring and I can't find any issues there.
Could this be a firmware issue with not detecting which sensor is being used?

whowechina, 2025-01-07:
I don't think it's a firmware issue.
Maybe check the mux.

Closed 2025-01-07.

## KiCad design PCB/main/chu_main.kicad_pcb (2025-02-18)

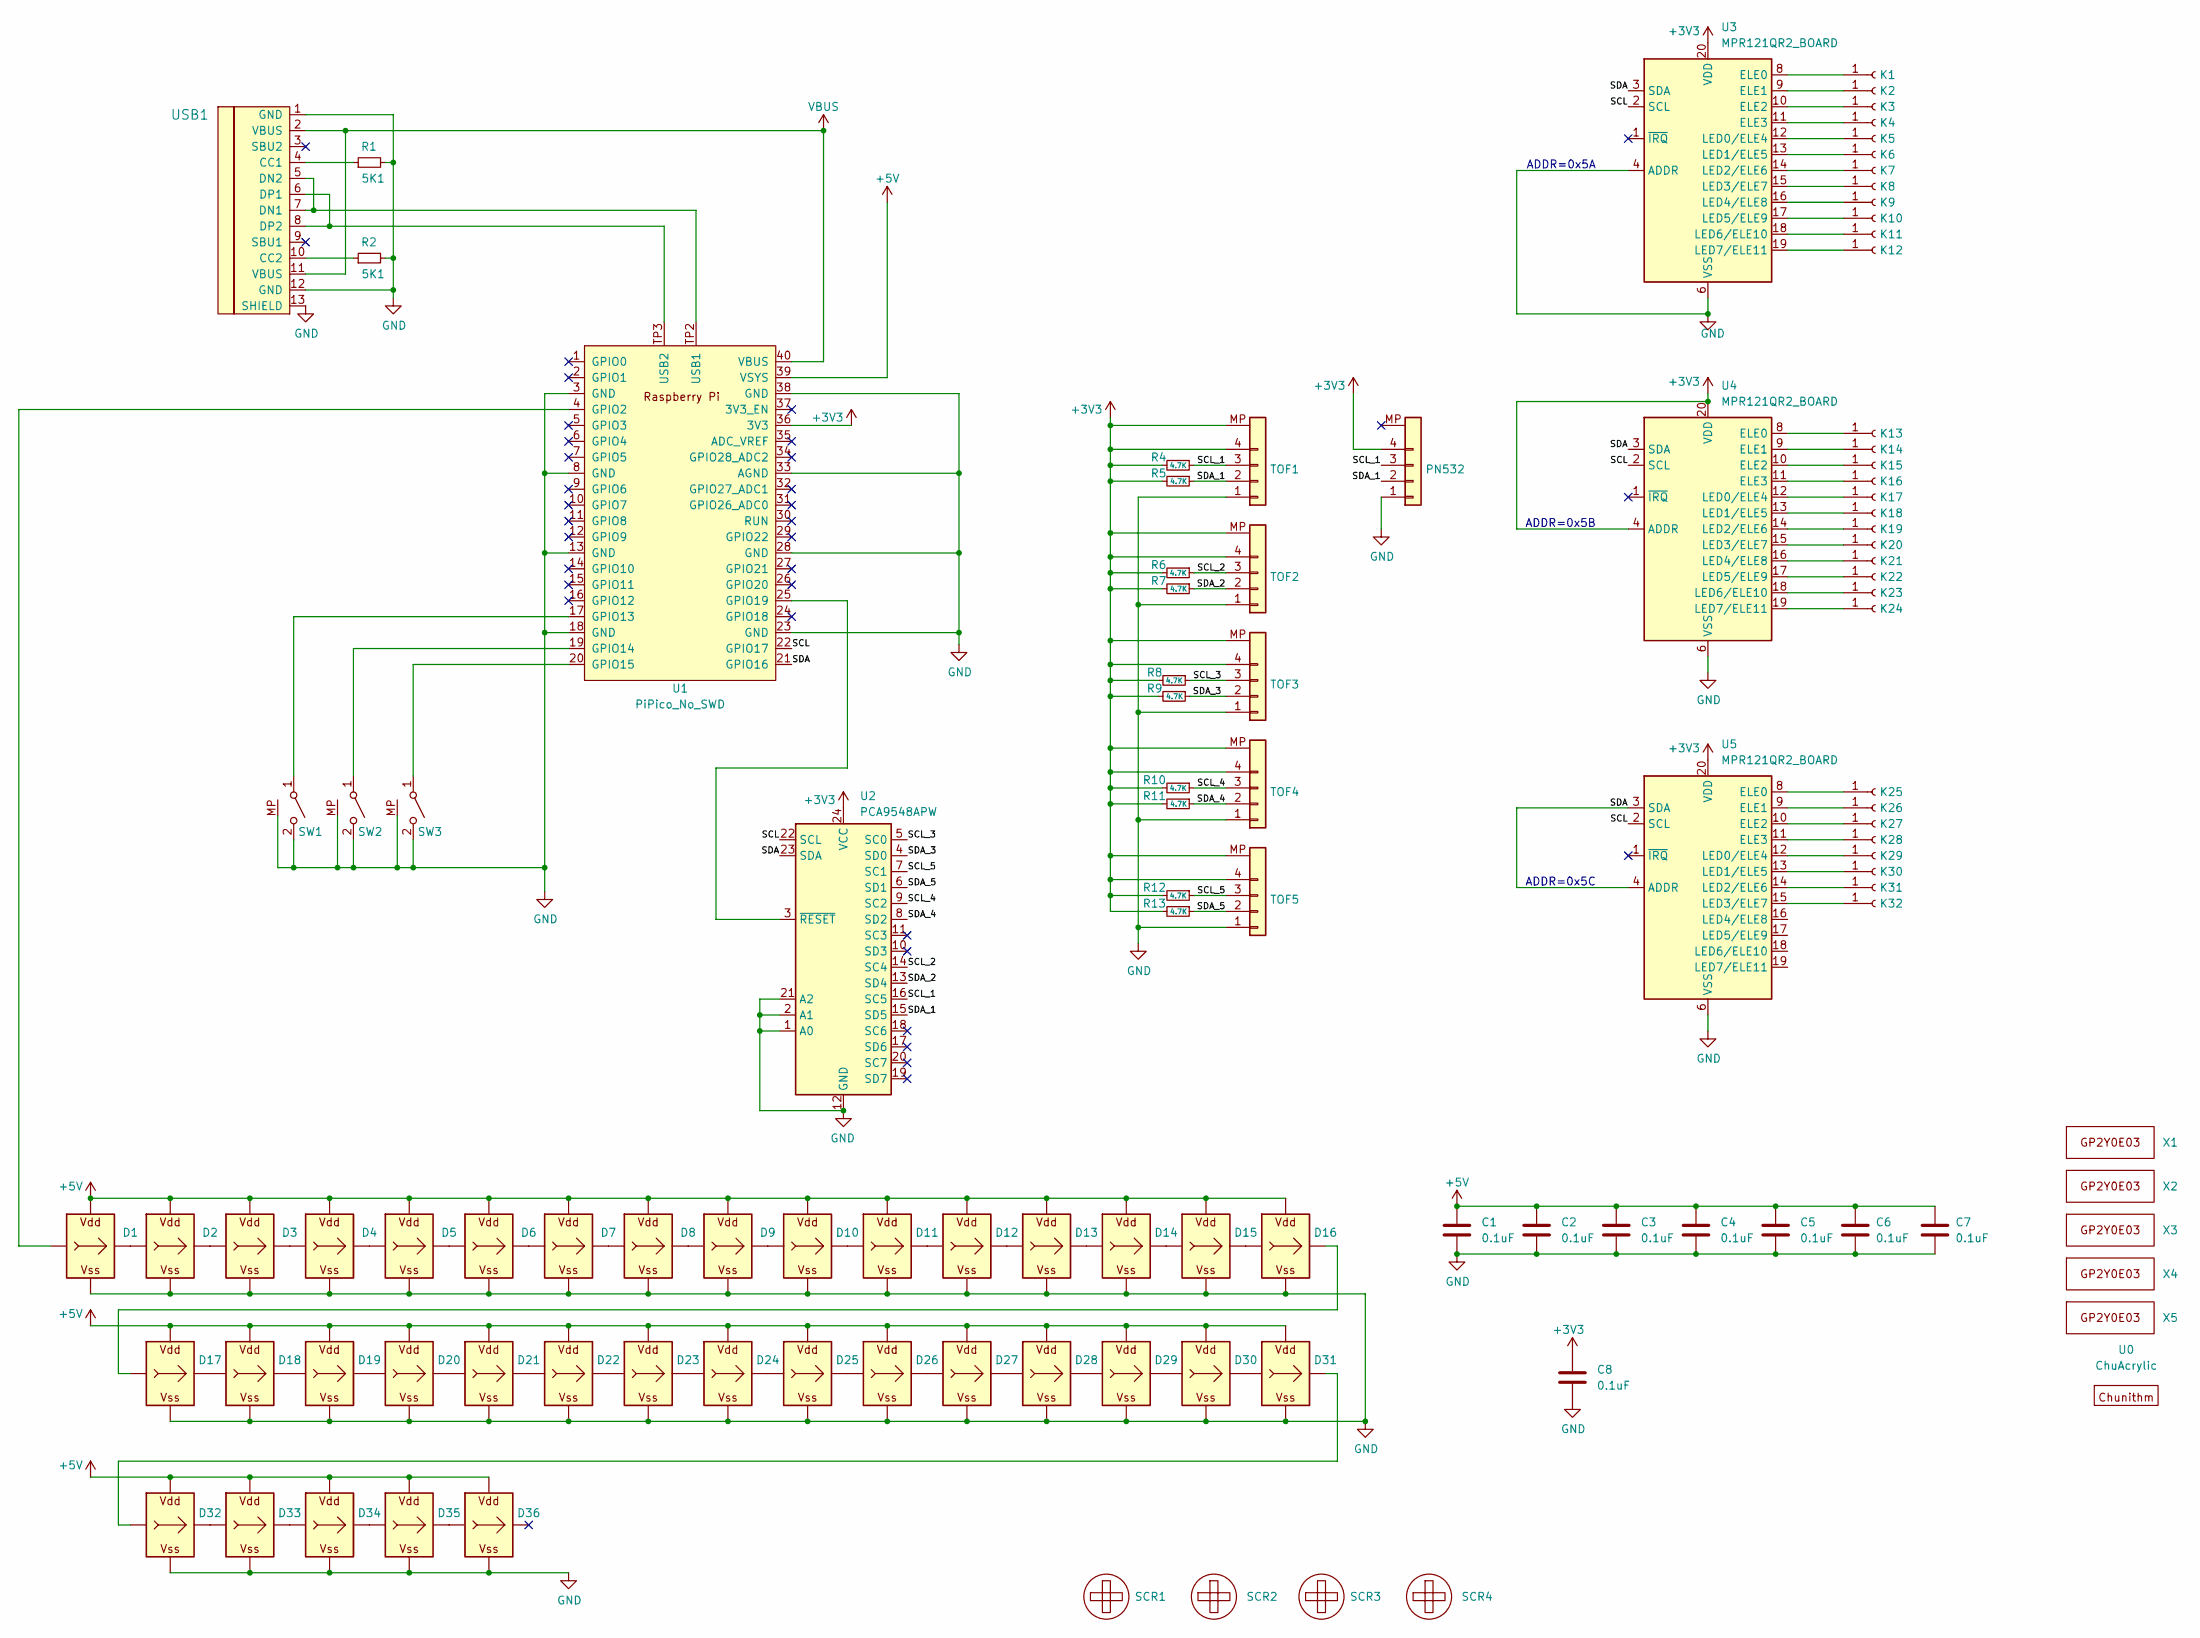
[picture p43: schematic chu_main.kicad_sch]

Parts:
C1, C2, C3, C4, C5, C6, C7, C8: 0.1uF; C_0603_1608Metric_Pad1.08x0.95mm_HandSolder
D1, D2, D3, D4, D5, D6, D7, D8, D9, D10, D11, D12, D13, D14, D15, D16, D17, D18, D19, D20, D21, D22, D23, D24, D25, D26, D27, D28, D29, D30, D31, D32, D33, D34, D35, D36: WS2812B_Unified; WS2812B-4020
K1, K2, K3, K4, K5, K6, K7, K8, K9, K10, K15, K16, K17, K18, K19, K20, K21, K22, K27, K28, K29, K30, K31, K32: Conn_01x01_Female; ChuKey
K11, K14, K23, K26: Conn_01x01_Female; ChuKeyBiasLeft
K12, K13, K24, K25: Conn_01x01_Female; ChuKeyBiasRight
PN532: TOF_I2C; SH1.0_4P_Solder_Combo
R1, R2: 5K1; R_0603_1608Metric_Pad0.98x0.95mm_HandSolder; LCSC C23186
R4, R5, R6, R7, R8, R9, R10, R11, R12, R13: 4.7K; R_0603_1608Metric_Pad0.98x0.95mm_HandSolder; LCSC C23186
SCR1, SCR2, SCR3, SCR4: ScrewHole; MountingHole_3.2mm_M3
SW1, SW2, SW3: SPST_EVQP4; SW_EVQ-P46B3M
TOF1, TOF2, TOF3, TOF4, TOF5: TOF_I2C; SH1.0_4P_Solder_Combo
U0: ChuAcrylic
U1: PiPico_No_SWD; RPi_Pico_SMD_Pins_No_SWD
U2: PCA9548APW; TSSOP-24_4.4x7.8mm_P0.65mm
U3, U4, U5: MPR121QR2_BOARD; MPR121_BOARD
USB1: U262-161N-4BVC11; HRO-TYPE-C-31-M-12-Assembly; LCSC C319148
X1, X2, X3, X4, X5: GP2Y0E03_REAL

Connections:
+3V3: C8.1, PN532.4, R4.2, R5.2, R6.2, R7.2, R8.2, R9.2, R10.2, R11.2, R12.2, R13.2, TOF1.4, TOF1.MP, TOF2.4, TOF2.MP, TOF3.4, TOF3.MP, TOF4.4, TOF4.MP, TOF5.4, TOF5.MP, U1.36 (3V3), U2.24 (VCC), U3.20 (VDD), U4.4 (ADDR), U4.20 (VDD), U5.20 (VDD)
+5V: C1.1, C2.1, C3.1, C4.1, C5.1, C6.1, C7.1, D1.V (VDD), D2.V (VDD), D3.V (VDD), D4.V (VDD), D5.V (VDD), D6.V (VDD), D7.V (VDD), D8.V (VDD), D9.V (VDD), D10.V (VDD), D11.V (VDD), D12.V (VDD), D13.V (VDD), D14.V (VDD), D15.V (VDD), D16.V (VDD), D17.V (VDD), D18.V (VDD), D19.V (VDD), D20.V (VDD), D21.V (VDD), D22.V (VDD), D23.V (VDD), D24.V (VDD), D25.V (VDD), D26.V (VDD), D27.V (VDD), D28.V (VDD), D29.V (VDD), D30.V (VDD), D31.V (VDD), D32.V (VDD), D33.V (VDD), D34.V (VDD), D35.V (VDD), D36.V (VDD), U1.39 (VSYS)
/SCL: U1.22 (GPIO17), U2.22 (SCL), U3.2 (SCL), U4.2 (SCL), U5.2 (SCL)
/SCL_1: PN532.3, R4.1, TOF1.3, U2.16 (SC5)
/SCL_2: R6.1, TOF2.3, U2.14 (SC4)
/SCL_3: R8.1, TOF3.3, U2.5 (SC0)
/SCL_4: R10.1, TOF4.3, U2.9 (SC2)
/SCL_5: R12.1, TOF5.3, U2.7 (SC1)
/SDA: U1.21 (GPIO16), U2.23 (SDA), U3.3 (SDA), U4.3 (SDA), U5.3 (SDA), U5.4 (ADDR)
/SDA_1: PN532.2, R5.1, TOF1.2, U2.15 (SD5)
/SDA_2: R7.1, TOF2.2, U2.13 (SD4)
/SDA_3: R9.1, TOF3.2, U2.4 (SD0)
/SDA_4: R11.1, TOF4.2, U2.8 (SD2)
/SDA_5: R13.1, TOF5.2, U2.6 (SD1)
GND: C1.2, C2.2, C3.2, C4.2, C5.2, C6.2, C7.2, C8.2, D1.G (VSS), D2.G (VSS), D3.G (VSS), D4.G (VSS), D5.G (VSS), D6.G (VSS), D7.G (VSS), D8.G (VSS), D9.G (VSS), D10.G (VSS), D11.G (VSS), D12.G (VSS), D13.G (VSS), D14.G (VSS), D15.G (VSS), D16.G (VSS), D17.G (VSS), D18.G (VSS), D19.G (VSS), D20.G (VSS), D21.G (VSS), D22.G (VSS), D23.G (VSS), D24.G (VSS), D25.G (VSS), D26.G (VSS), D27.G (VSS), D28.G (VSS), D29.G (VSS), D30.G (VSS), D31.G (VSS), D32.G (VSS), D33.G (VSS), D34.G (VSS), D35.G (VSS), D36.G (VSS), PN532.1, R1.2, R2.2, SW1.2 (B), SW1.MP, SW2.2 (B), SW2.MP, SW3.2 (B), SW3.MP, TOF1.1, TOF2.1, TOF3.1, TOF4.1, TOF5.1, U1.3 (GND), U1.8 (GND), U1.13 (GND), U1.18 (GND), U1.23 (GND), U1.28 (GND), U1.33 (AGND), U1.38 (GND), U2.1 (A0), U2.2 (A1), U2.12 (GND), U2.21 (A2), U3.4 (ADDR), U3.6 (VSS), U4.6 (VSS), U5.6 (VSS), USB1.1 (GND), USB1.12 (GND), USB1.13 (SHIELD)
unnamed: D1.I (In), U1.4 (GPIO2)
unnamed: D1.O (Out), D2.I (In)
unnamed: D2.O (Out), D3.I (In)
unnamed: D3.O (Out), D4.I (In)
unnamed: D4.O (Out), D5.I (In)
unnamed: D5.O (Out), D6.I (In)
unnamed: D6.O (Out), D7.I (In)
unnamed: D7.O (Out), D8.I (In)
unnamed: D8.O (Out), D9.I (In)
unnamed: D9.O (Out), D10.I (In)
unnamed: D10.O (Out), D11.I (In)
unnamed: D11.O (Out), D12.I (In)
unnamed: D12.O (Out), D13.I (In)
unnamed: D13.O (Out), D14.I (In)
unnamed: D14.O (Out), D15.I (In)
unnamed: D15.O (Out), D16.I (In)
unnamed: D16.O (Out), D17.I (In)
unnamed: D17.O (Out), D18.I (In)
unnamed: D18.O (Out), D19.I (In)
unnamed: D19.O (Out), D20.I (In)
unnamed: D20.O (Out), D21.I (In)
unnamed: D21.O (Out), D22.I (In)
unnamed: D22.O (Out), D23.I (In)
unnamed: D23.O (Out), D24.I (In)
unnamed: D24.O (Out), D25.I (In)
unnamed: D25.O (Out), D26.I (In)
unnamed: D26.O (Out), D27.I (In)
unnamed: D27.O (Out), D28.I (In)
unnamed: D28.O (Out), D29.I (In)
unnamed: D29.O (Out), D30.I (In)
unnamed: D30.O (Out), D31.I (In)
unnamed: D31.O (Out), D32.I (In)
unnamed: D32.O (Out), D33.I (In)
unnamed: D33.O (Out), D34.I (In)
unnamed: D34.O (Out), D35.I (In)
unnamed: D35.O (Out), D36.I (In)
unnamed: K1.1, U3.8 (ELE0)
unnamed: K2.1, U3.9 (ELE1)
unnamed: K3.1, U3.10 (ELE2)
unnamed: K4.1, U3.11 (ELE3)
unnamed: K5.1, U3.12 (LED0/ELE4)
unnamed: K6.1, U3.13 (LED1/ELE5)
unnamed: K7.1, U3.14 (LED2/ELE6)
unnamed: K8.1, U3.15 (LED3/ELE7)
unnamed: K9.1, U3.16 (LED4/ELE8)
unnamed: K10.1, U3.17 (LED5/ELE9)
unnamed: K11.1, U3.18 (LED6/ELE10)
unnamed: K12.1, U3.19 (LED7/ELE11)
unnamed: K13.1, U4.8 (ELE0)
unnamed: K14.1, U4.9 (ELE1)
unnamed: K15.1, U4.10 (ELE2)
unnamed: K16.1, U4.11 (ELE3)
unnamed: K17.1, U4.12 (LED0/ELE4)
unnamed: K18.1, U4.13 (LED1/ELE5)
unnamed: K19.1, U4.14 (LED2/ELE6)
unnamed: K20.1, U4.15 (LED3/ELE7)
unnamed: K21.1, U4.16 (LED4/ELE8)
unnamed: K22.1, U4.17 (LED5/ELE9)
unnamed: K23.1, U4.18 (LED6/ELE10)
unnamed: K24.1, U4.19 (LED7/ELE11)
unnamed: K25.1, U5.8 (ELE0)
unnamed: K26.1, U5.9 (ELE1)
unnamed: K27.1, U5.10 (ELE2)
unnamed: K28.1, U5.11 (ELE3)
unnamed: K29.1, U5.12 (LED0/ELE4)
unnamed: K30.1, U5.13 (LED1/ELE5)
unnamed: K31.1, U5.14 (LED2/ELE6)
unnamed: K32.1, U5.15 (LED3/ELE7)
unnamed: SW1.1 (A), U1.17 (GPIO13)
unnamed: SW2.1 (A), U1.19 (GPIO14)
unnamed: SW3.1 (A), U1.20 (GPIO15)
unnamed: U1.25 (GPIO19), U2.3 (~RESET)
unnamed: U1.TP2 (USB1), USB1.5 (DN2), USB1.7 (DN1)
unnamed: U1.TP3 (USB2), USB1.6 (DP1), USB1.8 (DP2)
unnamed: R1.1, USB1.4 (CC1)
unnamed: R2.1, USB1.10 (CC2)
VBUS: U1.40 (VBUS), USB1.2 (VBUS), USB1.11 (VBUS)

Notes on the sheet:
ADDR=0x5C
ADDR=0x5A
ADDR=0x5B

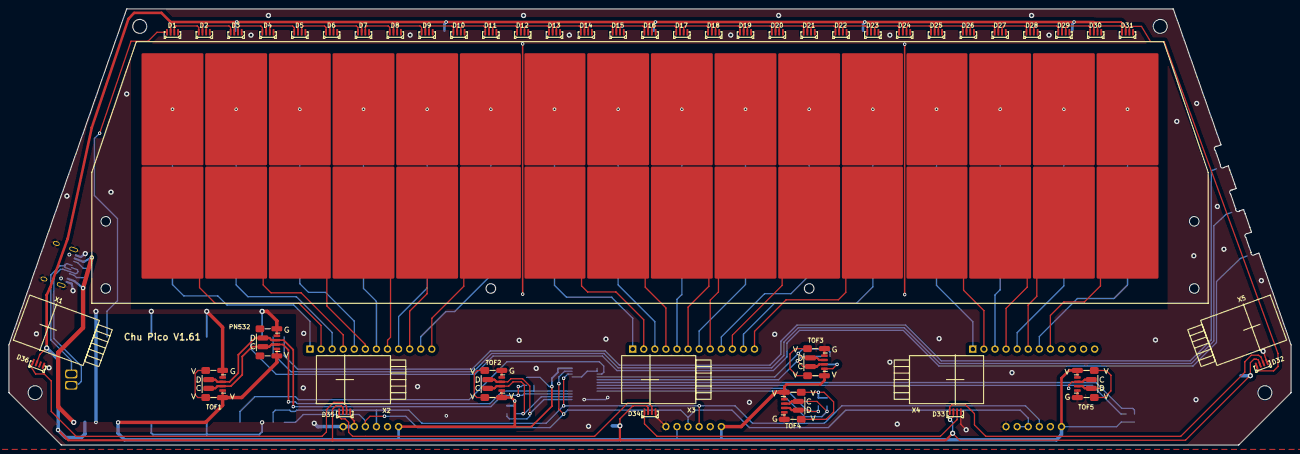
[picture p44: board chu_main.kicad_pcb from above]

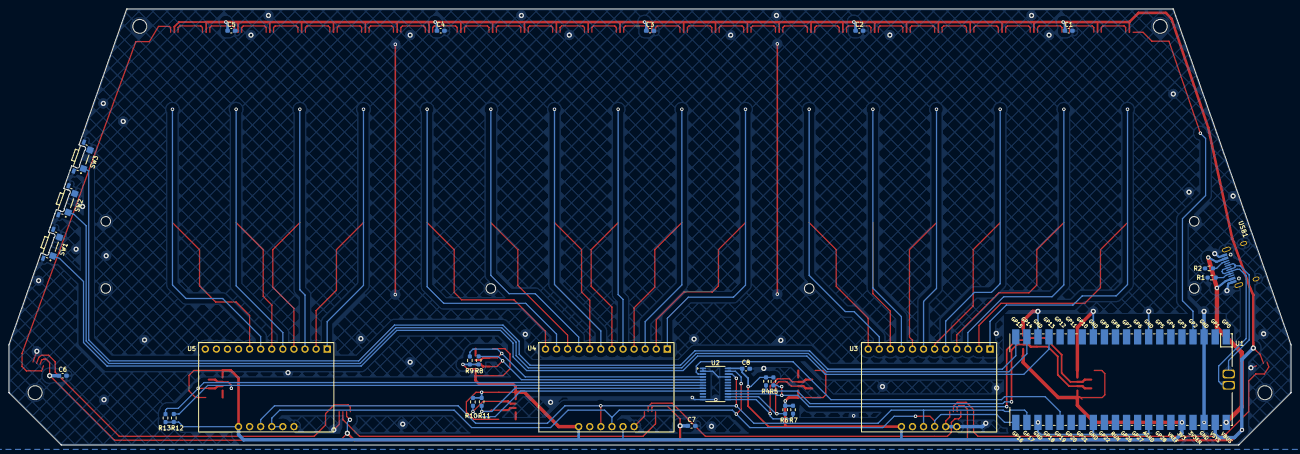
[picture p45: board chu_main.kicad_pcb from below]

Board: 2 copper layers, 294.0 x 100.0 mm, 113 parts (29 on the bottom side), 92 nets.

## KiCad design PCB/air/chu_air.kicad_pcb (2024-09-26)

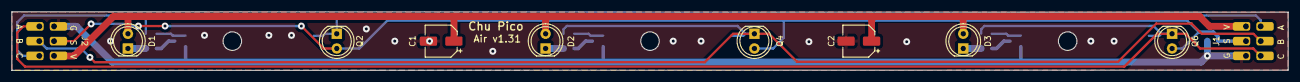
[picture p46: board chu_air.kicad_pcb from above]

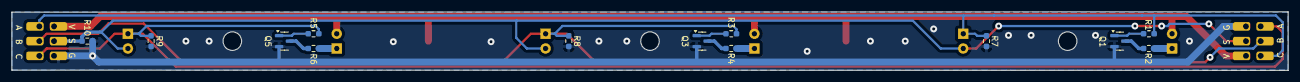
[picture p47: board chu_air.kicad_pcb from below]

Board: 2 copper layers, 220.0 x 10.1 mm, 23 parts (13 on the bottom side), 15 nets.

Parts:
C1, C2: 47uF; CP_Elec_5x5.9
D1, D2, D3: IR26-21C_L110_TR8; LED_D5.0mm_IRGrey
J1, J2: Conn_01x06_Socket; 6P_Air_Conn
Q1, Q3, Q5: 2N7002; SOT-23
Q2, Q4, Q6: Q_Photo_NPN; LED_D5.0mm_IRBlack
R1, R3, R5: 10R; R_0603_1608Metric_Pad0.98x0.95mm_HandSolder
R2, R4, R6: 1R; R_0603_1608Metric_Pad0.98x0.95mm_HandSolder
R7, R8, R9: 2K; R_0603_1608Metric_Pad0.98x0.95mm_HandSolder
R10: 10K; R_0603_1608Metric_Pad0.98x0.95mm_HandSolder

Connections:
+3.3V: C1.1, C2.1, D1.2 (A), D2.2 (A), D3.2 (A), J1.4, J2.4
/A: J1.1, J2.1, Q2.1 (C), R1.1, R7.1
/B: J1.2, J2.2, Q4.1 (C), R3.1, R8.1
/C: J1.3, J2.3, Q6.1 (C), R5.1, R9.1
/SIG: J1.5, J2.5, Q2.2 (E), Q4.2 (E), Q6.2 (E), R10.1
GND: C1.2, C2.2, J1.6, J2.6, Q1.2 (S), Q3.2 (S), Q5.2 (S), R7.2, R8.2, R9.2, R10.2
unnamed: D1.1 (K), R2.2
unnamed: D2.1 (K), R4.2
unnamed: D3.1 (K), R6.2
unnamed: Q1.3 (D), R2.1
unnamed: Q1.1 (G), R1.2
unnamed: Q3.3 (D), R4.1
unnamed: Q3.1 (G), R3.2
unnamed: Q5.3 (D), R6.1
unnamed: Q5.1 (G), R5.2

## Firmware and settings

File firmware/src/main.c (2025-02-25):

/*
 * Controller Main
 * WHowe <github.com/whowechina>
 */

#include <stdlib.h>
#include <stdint.h>
#include <stdbool.h>

#include "pico/stdio.h"
#include "pico/stdlib.h"
#include "bsp/board.h"
#include "pico/multicore.h"
#include "pico/bootrom.h"

#include "hardware/clocks.h"
#include "hardware/gpio.h"
#include "hardware/sync.h"
#include "hardware/structs/ioqspi.h"
#include "hardware/structs/sio.h"

#include "tusb.h"
#include "usb_descriptors.h"

#include "aime.h"
#include "nfc.h"

#include "board_defs.h"
#include "save.h"
#include "config.h"
#include "cli.h"
#include "commands.h"

#include "i2c_hub.h"
#include "slider.h"
#include "air.h"
#include "rgb.h"
#include "button.h"
#include "lzfx.h"

struct __attribute__((packed)) {
    uint16_t buttons; // 16 buttons; see JoystickButtons_t for bit mapping
    uint8_t  HAT;    // HAT switch; one nibble w/ unused nibble
    uint32_t axis;  // slider touch data
    uint8_t  VendorSpec;
} hid_joy, sent_hid_joy;

struct __attribute__((packed)) {
    uint8_t modifier;
    uint8_t keymap[15];
} hid_nkro, sent_hid_nkro;

void report_usb_hid()
{
    static uint64_t next_joy_time = 0;
    static uint64_t next_nkro_time = 0;

    if (tud_hid_ready()) {
        hid_joy.HAT = 0;
        hid_joy.VendorSpec = 0;
        if (chu_cfg->hid.joy) {
            if ((memcmp(&hid_joy, &sent_hid_joy, sizeof(hid_joy)) != 0) ||
                (time_us_64() > next_joy_time)) {
                if (tud_hid_report(REPORT_ID_JOYSTICK, &hid_joy, sizeof(hid_joy))) {
                    sent_hid_joy = hid_joy;
                    next_joy_time = time_us_64() + 2500; // forced report every 4ms
                }
            }
        }
        if (chu_cfg->hid.nkro) {
            if ((memcmp(&hid_nkro, &sent_hid_nkro, sizeof(hid_nkro)) != 0) ||
                (time_us_64() > next_nkro_time)) {
                if (tud_hid_n_report(0x02, 0, &sent_hid_nkro, sizeof(sent_hid_nkro))) {
                    sent_hid_nkro = hid_nkro;
                    next_nkro_time = time_us_64() + 2500; // forced report every 4ms
                }
            }
        }
    }
}

static void gen_joy_report()
{
    hid_joy.axis = 0;
    for (int i = 0; i < 16; i++) {
        if (slider_touched(i * 2)) {
            hid_joy.axis |= 1 << (30 - i * 2);
        }
        if (slider_touched(i * 2 + 1)) {
            hid_joy.axis |= 1 << (31 - i * 2);
        }

    }
    hid_joy.axis ^= 0x80808080; // some magic number from CrazyRedMachine
    uint16_t airmap = air_bitmap();

    /* to cope with Redboard mapping which I don't really understand why */
    hid_joy.buttons = ((airmap >> 1) & 0x07) | ((airmap & 0x01) << 3) | (airmap & 0x30);

    uint16_t aux = button_read();
    hid_joy.buttons |= (aux & 0x01) ? 0x200 : 0; // START
    hid_joy.buttons |= (aux & 0x02) ? 0x100 : 0; // SERVICE
    hid_joy.buttons |= (aux & 0x04) ? 0x1000 : 0; // TEST
}

const uint8_t keycode_table[128][2] = { HID_ASCII_TO_KEYCODE };
const uint8_t keymap[41 + 1] = NKRO_KEYMAP; // 32 keys, 6 air keys, 3 aux, 1 terminator
static void gen_nkro_report()
{
    for (int i = 0; i < 32; i++) {
        uint8_t code = keycode_table[keymap[i]][1];
        uint8_t byte = code / 8;
        uint8_t bit = code % 8;
        if (slider_touched(i)) {
            hid_nkro.keymap[byte] |= (1 << bit);
        } else {
            hid_nkro.keymap[byte] &= ~(1 << bit);
        }
    }

    uint16_t airmap = air_bitmap();
    for (int i = 0; i < 6; i++) {
        uint8_t code = keycode_table[keymap[32 + i]][1];
        uint8_t byte = code / 8;
        uint8_t bit = code % 8;
        if (airmap & (1 << i)) {
            hid_nkro.keymap[byte] |= (1 << bit);
        } else {
            hid_nkro.keymap[byte] &= ~(1 << bit);
        }
    }

    uint16_t aux = button_read();
    for (int i = 0; i < 3; i++) {
        uint8_t code = keycode_table[keymap[38 + i]][1];
        uint8_t byte = code / 8;
        uint8_t bit = code % 8;
        if (aux & (1 << i)) {
            hid_nkro.keymap[byte] |= (1 << bit);
        } else {
            hid_nkro.keymap[byte] &= ~(1 << bit);
        }
    }
}

static uint64_t last_hid_time = 0;

static void run_lights()
{
    uint64_t now = time_us_64();

    if (now - last_hid_time >= 1000000) {
        const uint32_t colors[] = {0x000000, 0x0000ff, 0xff0000, 0xffff00,
                                0x00ff00, 0x00ffff, 0xffffff};
        for (int i = 0; i < air_tof_num(); i++) {
            int d = air_tof_value(i);
            rgb_set_color(31 + i, colors[d]);
        }

        for (int i = 0; i < 15; i++) {
            uint32_t color = rgb32_from_hsv(i * 573 / 15, 255, 16);
            rgb_gap_color(i, color);
        }

        for (int i = 0; i < 16; i++) {
            bool r = slider_touched(i * 2);
            bool g = slider_touched(i * 2 + 1);
            rgb_set_color(30 - i * 2, rgb32(r ? 80 : 0, g ? 80 : 0, 0, false));
        }
    }

    uint32_t aime_color = aime_led_color();
    if (aime_color > 0) {
        uint8_t r = aime_color >> 16;
        uint8_t g = aime_color >> 8;
        uint8_t b = aime_color;

        uint32_t blink = now / 100000;
        aime_color = (blink & 1) ? rgb32(r, g, b, false) : 0;

        rgb_set_color(34, aime_color);
        rgb_set_color(35, aime_color);
    }
}

const int aime_intf = 1;
static void cdc_aime_putc(uint8_t byte)
{
    tud_cdc_n_write(aime_intf, &byte, 1);
    tud_cdc_n_write_flush(aime_intf);
}

static void aime_run()
{
    if (tud_cdc_n_available(aime_intf)) {
        uint8_t buf[32];
        uint32_t count = tud_cdc_n_read(aime_intf, buf, sizeof(buf));

        i2c_select(I2C_PORT, 1 << 5); // PN532 on IR1 (I2C mux chn 5)
        for (int i = 0; i < count; i++) {
            aime_feed(buf[i]);
        }
    }
}

static void runtime_ctrl()
{
    /* Just use long-press SERVICE to reset touch in runtime */
    static bool applied = false;
    static uint64_t press_time = 0;
    static bool last_svc_button = false;
    bool svc_button = button_read() & 0x02;

    if (svc_button) {
        if (!last_svc_button) {
            press_time = time_us_64();
            applied = false;
        }
        if (!applied && (time_us_64() - press_time > 2000000)) {
            slider_sensor_init();
            applied = true;
        }
    }

    last_svc_button = svc_button;
}

static mutex_t core1_io_lock;
static void core1_loop()
{
    while (1) {
        if (mutex_try_enter(&core1_io_lock, NULL)) {
            run_lights();
            rgb_update();
            mutex_exit(&core1_io_lock);
        }
        cli_fps_count(1);
        sleep_ms(1);
    }
}

static void core0_loop()
{
    uint64_t next_frame = time_us_64();
    while(1) {
        tud_task();

        cli_run();
        aime_run();
    
        save_loop();
        cli_fps_count(0);

        slider_update();
        air_update();
        button_update();

        gen_joy_report();
        gen_nkro_report();
        report_usb_hid();

        runtime_ctrl();

        sleep_until(next_frame);
        next_frame += 1000;
    }
}

/* if certain key pressed when booting, enter update mode */
static void update_check()
{
    const uint8_t pins[] = BUTTON_DEF;
    int pressed = 0;
    for (int i = 0; i < count_of(pins); i++) {
        uint8_t gpio = pins[i];
        gpio_init(gpio);
        gpio_set_function(gpio, GPIO_FUNC_SIO);
        gpio_set_dir(gpio, GPIO_IN);
        gpio_pull_up(gpio);
        sleep_ms(1);
        if (!gpio_get(gpio)) {
            pressed++;
        }
    }

    if (pressed >= 2) {
        sleep_ms(100);
        reset_usb_boot(0, 2);
        return;
    }
}

void init()
{
    sleep_ms(50);
    set_sys_clock_khz(150000, true);
    board_init();

    update_check();

    tusb_init();
    stdio_init_all();

    config_init();
    mutex_init(&core1_io_lock);
    save_init(0xca34cafe, &core1_io_lock);

    button_init();
    slider_init();
    air_init();
    rgb_init();

    nfc_attach_i2c(I2C_PORT);
    i2c_select(I2C_PORT, 1 << 5); // PN532 on IR1 (I2C mux chn 5)
    nfc_init();
    aime_init(cdc_aime_putc);
    aime_virtual_aic(chu_cfg->aime.virtual_aic);
    aime_sub_mode(chu_cfg->aime.mode);

    cli_init("chu_pico>", "\n   << Chu Pico Controller >>\n"
                            " https://github.com/whowechina\n\n");
    
    commands_init();
}

int main(void)
{
    init();
    multicore_launch_core1(core1_loop);
    core0_loop();
    return 0;
}

// Invoked when received GET_REPORT control request
// Application must fill buffer report's content and return its length.
// Return zero will cause the stack to STALL request
uint16_t tud_hid_get_report_cb(uint8_t itf, uint8_t report_id,
                               hid_report_type_t report_type, uint8_t *buffer,
                               uint16_t reqlen)
{
    printf("Get from USB %d-%d\n", report_id, report_type);
    return 0;
}

// Invoked when received SET_REPORT control request or
// received data on OUT endpoint ( Report ID = 0, Type = 0 )
void tud_hid_set_report_cb(uint8_t itf, uint8_t report_id,
                           hid_report_type_t report_type, uint8_t const *buffer,
                           uint16_t bufsize)
{
    if (report_type == HID_REPORT_TYPE_OUTPUT) {
        if (report_id == REPORT_ID_LED_SLIDER_16) {
            rgb_set_brg(0, buffer, bufsize / 3);
        } else if (report_id == REPORT_ID_LED_SLIDER_15) {
            rgb_set_brg(16, buffer, bufsize / 3);
        } else if (report_id == REPORT_ID_LED_TOWER_6) {
            rgb_set_brg(31, buffer, bufsize / 3);
        }
        last_hid_time = time_us_64();
        return;
    } 
    
    if (report_type == HID_REPORT_TYPE_FEATURE) {
        if (report_id == REPORT_ID_LED_COMPRESSED) {
            uint8_t buf[(48 + 45 + 6) * 3];
            unsigned int olen = sizeof(buf);
            if (lzfx_decompress(buffer + 1, buffer[0], buf, &olen) == 0) {
                rgb_set_brg(0, buf, olen / 3);
            }

            if (!chu_cfg->hid.joy) {
                chu_cfg->hid.joy = 1;
                config_changed();
            }
        }
        last_hid_time = time_us_64();
        return;
    }
}

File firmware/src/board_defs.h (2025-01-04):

/*
 * Chu Controller Board Definitions
 * WHowe <github.com/whowechina>
 */

#if defined BOARD_CHU_PICO

#define I2C_PORT i2c0
#define I2C_SDA 16
#define I2C_SCL 17
#define I2C_FREQ 620*1000

#define I2C_HUB_EN 19

#define TOF_MUX_LIST { 1, 2, 0, 4, 5 }

#define IR_GROUP_ABC_GPIO { 3, 4, 5 }
#define IR_SIG_ADC_CHANNEL { 0, 1 }

#define BUTTON_DEF { 13, 14, 15 }
#define RGB_MAIN_PIN 2
#define RGB_TOWER_LEFT_PIN 0
#define RGB_TOWER_RIGHT_PIN 1
#define RGB_ORDER GRB // or RGB

#define NKRO_KEYMAP "1aqz2swx3dec4frv5gtb6hyn7jum8ki90olp,.[]\\"
#else

#endif

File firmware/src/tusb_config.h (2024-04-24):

/*
 * The MIT License (MIT)
 *
 * Copyright (c) 2019 Ha Thach (tinyusb.org)
 *
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
 */

#ifndef _TUSB_CONFIG_H_
#define _TUSB_CONFIG_H_

#ifdef __cplusplus
extern "C" {
#endif

//--------------------------------------------------------------------
// COMMON CONFIGURATION
//--------------------------------------------------------------------

// defined by board.mk
#ifndef CFG_TUSB_MCU
#error CFG_TUSB_MCU must be defined
#endif

// RHPort number used for device can be defined by board.mk, default to port 0
#ifndef BOARD_DEVICE_RHPORT_NUM
#define BOARD_DEVICE_RHPORT_NUM 0
#endif

// RHPort max operational speed can defined by board.mk
// Default to Highspeed for MCU with internal HighSpeed PHY (can be port
// specific), otherwise FullSpeed
#ifndef BOARD_DEVICE_RHPORT_SPEED
#if (CFG_TUSB_MCU == OPT_MCU_LPC18XX || CFG_TUSB_MCU == OPT_MCU_LPC43XX ||   \
     CFG_TUSB_MCU == OPT_MCU_MIMXRT10XX || CFG_TUSB_MCU == OPT_MCU_NUC505 || \
     CFG_TUSB_MCU == OPT_MCU_CXD56)
#define BOARD_DEVICE_RHPORT_SPEED OPT_MODE_HIGH_SPEED
#else
#define BOARD_DEVICE_RHPORT_SPEED OPT_MODE_FULL_SPEED
#endif
#endif

// Device mode with rhport and speed defined by board.mk
#if BOARD_DEVICE_RHPORT_NUM == 0
#define CFG_TUSB_RHPORT0_MODE (OPT_MODE_DEVICE | BOARD_DEVICE_RHPORT_SPEED)
#elif BOARD_DEVICE_RHPORT_NUM == 1
#define CFG_TUSB_RHPORT1_MODE (OPT_MODE_DEVICE | BOARD_DEVICE_RHPORT_SPEED)
#else
#error "Incorrect RHPort configuration"
#endif

#ifndef CFG_TUSB_OS
#define CFG_TUSB_OS OPT_OS_NONE
#endif

// CFG_TUSB_DEBUG is defined by compiler in DEBUG build
// #define CFG_TUSB_DEBUG           0

/* USB DMA on some MCUs can only access a specific SRAM region with restriction
 * on alignment. Tinyusb use follows macros to declare transferring memory so
 * that they can be put into those specific section. e.g
 * - CFG_TUSB_MEM SECTION : __attribute__ (( section(".usb_ram") ))
 * - CFG_TUSB_MEM_ALIGN   : __attribute__ ((aligned(4)))
 */
#ifndef CFG_TUSB_MEM_SECTION
#define CFG_TUSB_MEM_SECTION
#endif

#ifndef CFG_TUSB_MEM_ALIGN
#define CFG_TUSB_MEM_ALIGN __attribute__((aligned(4)))
#endif

//--------------------------------------------------------------------
// DEVICE CONFIGURATION
//--------------------------------------------------------------------

#ifndef CFG_TUD_ENDPOINT0_SIZE
#define CFG_TUD_ENDPOINT0_SIZE 64
#endif

//------------- CLASS -------------//
#define CFG_TUD_HID 3
#define CFG_TUD_CDC 2
#define CFG_TUD_MSC 0
#define CFG_TUD_MIDI 0
#define CFG_TUD_VENDOR 0

// HID buffer size Should be sufficient to hold ID (if any) + Data
#define CFG_TUD_HID_EP_BUFSIZE 64

// CDC FIFO size of TX and RX
#define CFG_TUD_CDC_RX_BUFSIZE   (TUD_OPT_HIGH_SPEED ? 512 : 128)
#define CFG_TUD_CDC_TX_BUFSIZE   (TUD_OPT_HIGH_SPEED ? 512 : 128)

// CDC Endpoint transfer buffer size, more is faster
#define CFG_TUD_CDC_EP_BUFSIZE   (TUD_OPT_HIGH_SPEED ? 512 : 128)

#ifdef __cplusplus
}
#endif

#endif /* _TUSB_CONFIG_H_ */

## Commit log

2023-08-09 Work started, PCB shape and keyboard sensor done
    [Credit Button Assy (Groovy).step, EVQ-P1D05M.stp, J 2835.step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]
2023-08-13 Some updates (keypad, IR sensor firmware)
    [chu_main.kicad_pcb, chu_main.kicad_sch, gp2y0e03.3mf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]
2023-08-18 Layout progress 40%
    [chu_keypad_lgp.step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]
2023-08-19 Layoug progress 70%
    [chu_main.kicad_pcb, chu_main.kicad_sch]
2023-08-27 PCB v1 done
    [chu_main.kicad_sch]
2023-09-06 Small progress (issue in 2nd interface)
    [main.c, tusb_config.h]
2023-09-09 PCB v1.1 (LED footprint update)
    [chu_main.kicad_sch]
2023-09-09 PCB v1.2 (finetune capsense pad size)
2023-09-10 Ready to publish
    [chu_pico_base.stl, chu_pico_cover_base.stl, chu_pico_ir_cover.dwg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]
2023-09-10 More tolerance screw holes in base
    [chu_pico_base.stl]
2023-09-10 Better LGP fixer height
    [chu_pico_lgp_fixer.stl]
2023-09-10 Add timeout to I2C operations, so more stable
2023-09-10 More silicone pads
    [chu_pico_base.stl]
2023-09-16 Update readme for overclock I2C
2023-09-16 Finetune PCB and CAD files
    [chu_main.kicad_sch, chu_pico_base.stl, chu_pico_cover_base.stl]
2023-09-17 A little case CAD finetune
    [chu_pico_base.stl, chu_pico_top_cover.stl]
2023-09-18 Attempt on VL53L0X (not working)
    [vl53l0x.c]
2023-09-19 VL53L0x driver integrated but not fully tested
2023-09-22 Some cleanups
    [chu_main-B_Cu.gbl, chu_main-B_Mask.gbs, chu_main-B_Paste.gbp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]
2023-09-23 filter settings added
2023-09-24 Update README on MPR121 soldering
2023-09-27 More command line info and case insensitive
2023-09-28 LED brightness config
2023-10-03 Readme update on Bambu printer
2023-10-06 Add LED test firmware
2023-10-09 gp2y0e distance calculation correction
    [air.c]
2023-10-14 Crossreference to Mai Pico
2023-10-15 PCB v1.4 (reduce crosstalk)
    [chu_main.kicad_pcb, chu_main.kicad_sch]
2023-10-17 PN532 Small Antenna Attempt
    [pn532_ant.kicad_pcb, pn532_ant.kicad_sch]
2023-10-21 AIME carder reader option in CAD files
    [chu_pico_cover.stl, chu_pico_cover_aime.stl]
2023-10-21 PCB v1.5 for dedicate PN532 pads
    [chu_main.kicad_pcb, chu_main.kicad_sch, pn532_ant.kicad_pcb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]
2023-10-22 AIME reader (50%, not working)
    [main.c, tusb_config.h]
2023-11-19 Fix VL53L0X timeout issue
    [vl53l0x.c]
2023-11-19 Fix USB failure due to VL53L0x wait
    [vl53l0x.c]
2023-11-19 VL53L0x update but still crosstalks and shortsight
    [air.c, vl53l0x.c]
2023-11-20 VL53L0x with "shortsight" issue, NFC included
    [air.c, vl53l0x.c]
2023-11-22 VL53L0x "shortsighted" fixed
    [chu_pico_cover.stl, chu_pico_cover_aime.stl]
2023-12-09 Fix minor buffer over read issue
    [mpr121.c, slider.c]
2023-12-10 Minor lint fix for PCB project
    [chu_main.kicad_pcb]
2024-01-12 Better resistor values
2024-03-17 Attach to latest aic pico
2024-03-29 IR based air module PCB
    [chu_air.kicad_pcb, chu_air.kicad_sch]
2024-04-24 Update to latest AIC Pico library
2024-04-30 Update to latest aic pico lib
2024-06-04 Remove chu_air PCB as it's not ready
2024-07-15 Cross-reference to new Groove Pico
2024-08-27 Added bevel to the LGP fixer to make room for R1/R2
    [chu_pico_lgp_fixer.stl]
2024-09-08 Another attempt of chu air
    [chu_air.kicad_pcb, chu_air.kicad_sch]
2024-09-19 Air PCB v1.3
    [chu_air.kicad_pcb, chu_air.kicad_sch]
2024-09-20 Update component models in air PCB
    [chu_air.kicad_sch]
2024-09-23 Air PCB orientation
2024-09-26 Air PCB v1.31 (update screw clearance)
    [chu_air.kicad_pcb]
2024-11-02 Upload missing picture of air pcb
2024-11-02 Fix air key ordering
    [main.c]
2024-11-13 Cross-reference to Ju Pico
2024-11-17 Sensor status in raw command
2024-11-29 Support latest pico sdk
2024-12-02 Fix i2c write timing
    [vl53l0x.c]
2024-12-23 Minor update with cross-ref to bishi pico
2024-12-23 Tweak option to skip splitter LED
    [commands.c]
2024-12-27 Chu main PCB v1.6
    [EVQ-P46B3M.step, chu_main.kicad_pcb, chu_main.kicad_sch]
2025-01-04 Support for 3 aux buttons
2025-01-18 fix: address overflow and persistance bugs with filter config
    [commands.c]
2025-02-03 Minor change for previous filter bug fix
    [commands.c]
2025-02-03 Sync to latest aic pico library
2025-02-13 Housing supports 3 aux buttons
    [chu_pico_base.stl, chu_pico_cover_base.stl]
2025-02-13 3 aux buttons in README
2025-02-16 Fix minor interference in housing base
    [chu_pico_base.stl]
2025-02-18 PCB v1.61 (fix TOF silkscreen marks)
    [chu_main.kicad_pcb]
2025-03-02 Fix sensor status display
    [slider.c]
2025-04-04 Cross-reference to Nos Pico
2025-05-16 Notes on LEDs in older PCB
2025-06-01 Add usb clearance to base, add light shade to cover
    [chu_pico_base.stl, chu_pico_cover.stl]
2025-07-29 Reset buffer before reading MPR121
    [mpr121.c]
2026-03-11 Larger pads and minor updates
    [chu_pico_cover.stl, chu_pico_cover_aime.stl, chu_pico_cover_base.stl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]
2026-03-23 Sync to latest aic pico lib
2026-03-30 Faster IR slew rate to minimize mosfet gray zone time
2026-06-02 Description of extra screws
